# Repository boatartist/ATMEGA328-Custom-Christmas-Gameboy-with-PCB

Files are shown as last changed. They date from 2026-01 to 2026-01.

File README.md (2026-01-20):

# ATMEGA328-Custom-Christmas-Gameboy-with-PCB



For Christmas every year, I try to make each member of my family something unique, showing off my technical ability and giving them something personalised. However, as I get older and my skills improve, the time taken to make an original gift for all 7+ members of my close family increases exponentially. Instead, I thought I might try making everyone the same thing this year, and customising the product to fit their tastes. I landed on a gameboy-style Arduino-based console, possibly with only one game each, with unique 3D-printed enclosures and different games to match each person. Because I'm cheap, we will not be using reliable and standard OLED displays and an Arduino Nano or similar, instead I've gone for an obscure TFT-LCD from Digikey and an ATMEGA328-PU chip to achieve the same goals. 

Of course, there will also be a custom PCB (with factory PCB assembly because my soldering iron is rubbish) to house the display, buttons and microcontroller. And, of course, I have hugely overestimated my own knowledge and gone down an extreme rabbit-hole of fuse-bits and ISPs and oscillators thinking I'd broken the chips. If you're using Arduino ISP, be warned because it will cause a ridiculous amount of problems.

## Parts
All links to where I ordered from (I ordered for 10 modules), which came out to about AUD$250 with shipping, PCB and assembly, but the parts themselves are the cheapest I could find. Probably shouldn't have ordered from 3 separate sources lol, but the $25 each is still cheaper than any existing product. 

Each board contains: 
- [ATMEGA328-PU](https://www.digikey.com.au/en/products/detail/microchip-technology/ATMEGA328-PU/2271026)
- 6 x [3.3K Ohm through-hole resistor](https://www.digikey.com.au/en/products/detail/koa-speer-electronics-inc/MF1-4LCT52R332J/21680116)
- 6 x [2.2K Ohm through-hole resistor](https://www.digikey.com.au/en/products/detail/te-connectivity-passive-product/CFR50J2K2/2380663)
- [Battery holder for 3 x AAA batteries](https://www.digikey.com.au/en/products/detail/keystone-electronics/2479/303824)
- [320x240 ST7789 TFT LCD](https://www.lcsc.com/product-detail/C5329582.html)
- 6 x [push buttons](https://www.lcsc.com/product-detail/C22375351.html)
- [IC Socket for ATMEGA328](https://www.lcsc.com/product-detail/C72125.html)
- [FFC Connector for display](https://www.lcsc.com/product-detail/C2911796.html)

## Steps to program using [ISP](https://www.jaycar.com.au/duinotech-isp-programmer-for-arduino-and-avr/p/XC4627)
1. Set up ISP (In-System Programmer) according to [manual](https://media.jaycar.com.au/product/resources/XC4627_manualMain_86841.pdf), configuring with latest version of USB-ASP
2. Install [AVRDUDESS](https://atmega32-avr.com/avrdudess-a-gui-for-avrdude/) and set fuses and settings to match screenshots exactly  
3. Download gameboy_snake.hex file and select it to be flashed
4. Wire ATMega328 on breadboard to connect to ISP pins
  
  | ISP Pin       | ATMega328 Pin |
  | ------------- | ------------- |
  | MISO          | 18            |
  | MOSI          | 17            |
  | SCK           | 19            |
  | RST           | 1             |
  | VCC           | 7             |
  | GND           | 8             |

5. Hit **Program** on AVRDUDESS and watch code flash to the chip
6. Disconnect ATMega328 from breadboard and plug into PCB, attach batteries and enjoy! 

## Wiring diagram
Schematic_gameboy-christmas-project-with-ATMEGA328-and-MF128128F15-BFW_2026-01-20

## PCB
Download Gerber and/or order details from files

Photo-View_2025-11-28
<?xml version="1.0" encoding="utf-8" standalone="no"?><svg xmlns="http://www.w3.org/2000/svg" xmlns:xlink="http://www.w3.org/1999/xlink" width="50.08890017780036mm" height="125.06985013970029mm" viewBox="4010 3386 197.2 492.4"><rect x="4010" y="3386" width="197.2" height="492.4" fill="#FFFFFF" stroke="none"/><defs xmlns="http://www.w3.org/2000/svg" id="patterns"><pattern id="gridPattern" x="4000" y="3000" width="10" height="10" patternUnits="userSpaceOnUse"><rect id="gridCell" x="0" y="0" width="0.7143" height="0.7143" fill="#FFFFFF" stroke="none"/></pattern><pattern id="gridPattern2" x="4000.7143" y="3000.7143" width="10" height="10" patternUnits="userSpaceOnUse"><path id="gridCell2" d="M10 0V10H-10" fill="none" stroke="#FFFFFF" stroke-width="0.7143" stroke-opacity="0.6"/></pattern><marker id="arrowOnStart" orient="auto" refY="0" refX="0" style="overflow:visible" markerUnits="strokeWidth"><path d="M 2,0 l 4,-2, 0,4 z" stroke-width="6"/></marker><marker id="arrowOnEnd" orient="auto" refY="0" refX="0" style="overflow:visible" markerUnits="strokeWidth"><path d="M -2,0 l -4,-2, 0,4 z" stroke-width="6"/></marker><marker id="arrowOnStartChrome" orient="auto" refY="0" refX="0" style="overflow:visible" markerUnits="strokeWidth"><path d="M 2,0 l 4,-2, 0,4 z" stroke-width="3" stroke="#FFFFFF"/></marker><marker id="arrowOnEndChrome" orient="auto" refY="0" refX="0" style="overflow:visible" markerUnits="strokeWidth"><path d="M -2,0 l -4,-2, 0,4 z" stroke-width="3" stroke="#FFFFFF"/></marker><svg id="icon-lock" title="Unlock" viewBox="0 0 20 20" height="20" width="20"><path stroke="#F0F" stroke-width="2" style="cursor:pointer;fill-opacity:.001;fill:#fff" d="M 5 7 C 5 -1 15 -1 15 7L1 7 1 19 19 19 19 7 15 7"/></svg><mask id="multiLayerMask" maskUnits="userSpaceOnUse" x="4020" y="3396" width="177.2" height="472.4"><path d="M4035.7493 3868.44,4035.3938 3868.4359,4035.3881 3868.4357,4035.0416 3868.4241,4035.036 3868.4238,4034.6849 3868.404,4034.6794 3868.4036,4034.3336 3868.3762,4034.328 3868.3757,4033.9828 3868.3407,4033.9771 3868.3401,4033.6243 3868.2961,4033.6186 3868.2953,4033.2793 3868.2451,4033.2739 3868.2443,4032.9234 3868.1846,4032.9178 3868.1835,4032.5809 3868.1181,4032.5754 3868.117,4032.2322 3868.0425,4032.2267 3868.0412,4031.8857 3867.959,4031.8801 3867.9576,4031.5416 3867.8677,4031.5363 3867.8662,4031.2031 3867.7699,4031.1976 3867.7682,4030.8647 3867.6636,4030.8595 3867.6619,4030.5274 3867.5494,4030.522 3867.5475,4030.1925 3867.4275,4030.1871 3867.4255,4029.8629 3867.2989,4029.8577 3867.2968,4029.538 3867.1638,4029.5328 3867.1616,4029.2094 3867.0183,4029.2043 3867.0159,4028.8911 3866.8688,4028.8861 3866.8663,4028.5712 3866.7096,4028.566 3866.707,4028.2579 3866.5447,4028.2531 3866.542,4027.9474 3866.3722,4027.9425 3866.3695,4027.6422 3866.1938,4027.6373 3866.1908,4027.3381 3866.0063,4027.3333 3866.0033,4027.0435 3865.8155,4027.039 3865.8125,4026.745 3865.6127,4026.7403 3865.6094,4026.4594 3865.409,4026.4549 3865.4057,4026.1728 3865.1946,4026.1683 3865.1912,4025.8984 3864.9796,4025.894 3864.976,4025.6166 3864.7482,4025.6123 3864.7446,4025.3533 3864.522,4025.3491 3864.5183,4025.0882 3864.2837,4025.084 3864.2799,4024.8293 3864.0401,4024.8253 3864.0363,4024.5751 3863.79,4024.571 3863.7859,4024.3292 3863.5367,4024.3253 3863.5327,4024.0889 3863.278,4024.0852 3863.2739,4023.8503 3863.009,4023.8466 3863.0048,4023.6243 3862.7426,4023.6206 3862.7383,4023.3976 3862.4627,4023.3942 3862.4582,4023.1824 3862.1844,4023.179 3862.1799,4022.9715 3861.8984,4022.9683 3861.8939,4022.7651 3861.605,4022.7619 3861.6004,4022.569 3861.3125,4022.5659 3861.3078,4022.3796 3861.0159,4022.3765 3861.011,4022.195 3860.7116,4022.1922 3860.7068,4022.0156 3860.4005,4022.0128 3860.3955,4021.8473 3860.0927,4021.8447 3860.0877,4021.6827 3859.7749,4021.6802 3859.7699,4021.5282 3859.4593,4021.5258 3859.4542,4021.3762 3859.1301,4021.3739 3859.125,4021.2371 3858.8105,4021.2348 3858.8052,4021.1025 3858.4807,4021.1005 3858.4755,4020.9772 3858.153,4020.9752 3858.1477,4020.8556 3857.8123,4020.8537 3857.8069,4020.7462 3857.4821,4020.7446 3857.4768,4020.6401 3857.1361,4020.6385 3857.1307,4020.5453 3856.8,4020.5438 3856.7945,4020.4554 3856.4514,4020.4541 3856.446,4020.3751 3856.1089,4020.3738 3856.1033,4020.3021 3855.7617,4020.301 3855.7562,4020.2363 3855.4102,4020.2354 3855.4046,4020.1794 3855.0624,4020.1785 3855.0568,4020.1302 3854.7123,4020.1294 3854.7067,4020.0885 3854.3589,4020.0879 3854.3533,4020.0547 3854.0033,4020.0543 3853.9977,4020.0291 3853.6509,4020.0288 3853.6451,4020.0115 3853.2947,4020.0113 3853.2891,4020.002 3852.9426,4020.0019 3852.9377,4019.9999 3852.691,4020 3852.689,4020 3411.7504,4019.9999 3411.7476,4020.004 3411.3938,4020.0042 3411.3881,4020.0158 3411.0416,4020.0161 3411.036,4020.0359 3410.6849,4020.0363 3410.6794,4020.0637 3410.3336,4020.0642 3410.328,4020.0992 3409.9828,4020.0998 3409.9771,4020.1438 3409.6243,4020.1446 3409.6186,4020.1948 3409.2793,4020.1956 3409.2739,4020.2553 3408.9234,4020.2564 3408.9178,4020.3218 3408.5809,4020.3229 3408.5754,4020.3974 3408.2322,4020.3987 3408.2267,4020.4809 3407.8857,4020.4823 3407.8801,4020.5722 3407.5416,4020.5737 3407.5363,4020.67 3407.2031,4020.6717 3407.1976,4020.7763 3406.8647,4020.778 3406.8595,4020.8905 3406.5274,4020.8924 3406.522,4021.0124 3406.1925,4021.0144 3406.1871,4021.141 3405.8629,4021.1431 3405.8577,4021.2761 3405.538,4021.2783 3405.5328,4021.4216 3405.2094,4021.424 3405.2043,4021.5711 3404.8911,4021.5736 3404.8861,4021.7303 3404.5712,4021.7329 3404.566,4021.8952 3404.2579,4021.8979 3404.2531,4022.0677 3403.9474,4022.0704 3403.9425,4022.2461 3403.6422,4022.2491 3403.6373,4022.4336 3403.3381,4022.4366 3403.3333,4022.6244 3403.0435,4022.6274 3403.039,4022.8272 3402.745,4022.8305 3402.7403,4023.0309 3402.4594,4023.0342 3402.4549,4023.2453 3402.1728,4023.2487 3402.1683,4023.4593 3401.8996,4023.4628 3401.8952,4023.6917 3401.6165,4023.6953 3401.6123,4023.9179 3401.3533,4023.9216 3401.3491,4024.1562 3401.0882,4024.16 3401.084,4024.3998 3400.8293,4024.4036 3400.8253,4024.6499 3400.5751,4024.654 3400.571,4024.9032 3400.3292,4024.9072 3400.3253,4025.1619 3400.0889,4025.166 3400.0852,4025.4309 3399.8503,4025.4351 3399.8466,4025.6973 3399.6243,4025.7016 3399.6206,4025.9772 3399.3976,4025.9817 3399.3942,4026.2555 3399.1824,4026.26 3399.179,4026.5415 3398.9715,4026.546 3398.9683,4026.8349 3398.7651,4026.8395 3398.7619,4027.1274 3398.569,4027.1321 3398.5659,4027.424 3398.3796,4027.4289 3398.3765,4027.7283 3398.195,4027.7331 3398.1922,4028.0394 3398.0156,4028.0444 3398.0128,4028.3472 3397.8473,4028.3522 3397.8447,4028.665 3397.6827,4028.67 3397.6802,4028.9806 3397.5282,4028.9857 3397.5257,4029.309 3397.3765,4029.314 3397.3743,4029.6293 3397.2371,4029.6347 3397.2348,4029.9592 3397.1025,4029.9644 3397.1005,4030.2869 3396.9772,4030.2922 3396.9752,4030.6276 3396.8556,4030.633 3396.8537,4030.9578 3396.7462,4030.9631 3396.7446,4031.3038 3396.6401,4031.3092 3396.6385,4031.6399 3396.5453,4031.6454 3396.5438,4031.9885 3396.4554,4031.9939 3396.4541,4032.331 3396.3751,4032.3366 3396.3738,4032.6782 3396.3021,4032.6837 3396.301,4033.0297 3396.2363,4033.0353 3396.2354,4033.3775 3396.1794,4033.3831 3396.1785,4033.7276 3396.1302,4033.7332 3396.1294,4034.081 3396.0885,4034.0866 3396.0879,4034.4366 3396.0547,4034.4422 3396.0543,4034.789 3396.0291,4034.7948 3396.0288,4035.1452 3396.0115,4035.1508 3396.0113,4035.4973 3396.002,4035.5022 3396.0019,4035.7489 3395.9999,4035.7509 3396,4181.4128 3396,4181.4156 3395.9999,4181.7711 3396.004,4181.7768 3396.0042,4182.1233 3396.0158,4182.1289 3396.0161,4182.48 3396.0359,4182.4855 3396.0363,4182.8313 3396.0637,4182.8369 3396.0642,4183.1821 3396.0992,4183.1878 3396.0998,4183.5406 3396.1438,4183.5463 3396.1446,4183.8856 3396.1948,4183.891 3396.1956,4184.2415 3396.2553,4184.2471 3396.2564,4184.584 3396.3218,4184.5895 3396.3229,4184.9327 3396.3974,4184.9382 3396.3987,4185.2792 3396.4809,4185.2848 3396.4823,4185.6233 3396.5722,4185.6286 3396.5737,4185.9618 3396.67,4185.9673 3396.6717,4186.3002 3396.7763,4186.3054 3396.778,4186.6375 3396.8905,4186.6429 3396.8924,4186.9724 3397.0124,4186.9778 3397.0144,4187.302 3397.141,4187.3072 3397.1431,4187.6269 3397.2761,4187.6321 3397.2783,4187.9555 3397.4216,4187.9606 3397.424,4188.2738 3397.5711,4188.2788 3397.5736,4188.5937 3397.7303,4188.5989 3397.7329,4188.907 3397.8952,4188.9118 3397.8979,4189.2175 3398.0677,4189.2224 3398.0704,4189.5227 3398.2461,4189.5276 3398.2491,4189.8268 3398.4336,4189.8316 3398.4366,4190.1214 3398.6244,4190.1259 3398.6274,4190.4199 3398.8272,4190.4246 3398.8305,4190.7055 3399.0309,4190.71 3399.0342,4190.9921 3399.2453,4190.9966 3399.2487,4191.2665 3399.4603,4191.2709 3399.4639,4191.5483 3399.6917,4191.5526 3399.6953,4191.8116 3399.9179,4191.8158 3399.9216,4192.0767 3400.1562,4192.0809 3400.16,4192.3356 3400.3998,4192.3396 3400.4036,4192.5898 3400.6499,4192.5939 3400.654,4192.8357 3400.9032,4192.8396 3400.9072,4193.076 3401.1619,4193.0797 3401.166,4193.3146 3401.4309,4193.3183 3401.4351,4193.5406 3401.6973,4193.5443 3401.7016,4193.7673 3401.9772,4193.7707 3401.9817,4193.9825 3402.2555,4193.9859 3402.26,4194.1924 3402.5401,4194.1956 3402.5446,4194.3998 3402.8349,4194.403 3402.8395,4194.5959 3403.1274,4194.599 3403.1321,4194.7853 3403.424,4194.7884 3403.4289,4194.9699 3403.7283,4194.9727 3403.7331,4195.1493 3404.0394,4195.1521 3404.0444,4195.3176 3404.3472,4195.3202 3404.3522,4195.4822 3404.665,4195.4847 3404.67,4195.6367 3404.9806,4195.6391 3404.9857,4195.7887 3405.3098,4195.791 3405.3149,4195.9278 3405.6294,4195.9301 3405.6347,4196.0624 3405.9592,4196.0644 3405.9644,4196.1877 3406.2869,4196.1897 3406.2922,4196.3093 3406.6276,4196.3111 3406.6329,4196.4181 3406.9559,4196.4199 3406.9613,4196.5249 3407.3038,4196.5264 3407.3092,4196.6196 3407.6399,4196.6211 3407.6454,4196.7095 3407.9885,4196.7108 3407.9939,4196.7898 3408.331,4196.7911 3408.3366,4196.8628 3408.6782,4196.8639 3408.6837,4196.9286 3409.0297,4196.9295 3409.0353,4196.9855 3409.3775,4196.9864 3409.3831,4197.0347 3409.7276,4197.0355 3409.7332,4197.0764 3410.081,4197.077 3410.0866,4197.1102 3410.4366,4197.1106 3410.4422,4197.1358 3410.789,4197.1361 3410.7948,4197.1534 3411.1452,4197.1536 3411.1508,4197.1629 3411.4973,4197.163 3411.5021,4197.165 3411.7449,4197.165 3852.6906,4197.1609 3853.0461,4197.1607 3853.0518,4197.1491 3853.3983,4197.1488 3853.4039,4197.129 3853.755,4197.1286 3853.7605,4197.1012 3854.1063,4197.1007 3854.1119,4197.0657 3854.4571,4197.0651 3854.4628,4197.0211 3854.8156,4197.0203 3854.8213,4196.9701 3855.1606,4196.9693 3855.166,4196.9096 3855.5165,4196.9085 3855.5221,4196.8431 3855.859,4196.842 3855.8645,4196.7675 3856.2077,4196.7662 3856.2132,4196.684 3856.5542,4196.6826 3856.5598,4196.5927 3856.8983,4196.5912 3856.9036,4196.4949 3857.2368,4196.4932 3857.2423,4196.3886 3857.5752,4196.3869 3857.5804,4196.2744 3857.9125,4196.2725 3857.9179,4196.1525 3858.2474,4196.1505 3858.2528,4196.0239 3858.577,4196.0218 3858.5822,4195.8888 3858.9019,4195.8866 3858.9071,4195.7433 3859.2305,4195.7409 3859.2356,4195.5938 3859.5488,4195.5913 3859.5538,4195.4346 3859.8687,4195.432 3859.8739,4195.2697 3860.182,4195.267 3860.1868,4195.0972 3860.4925,4195.0945 3860.4974,4194.9188 3860.7977,4194.9158 3860.8026,4194.7313 3861.1018,4194.7283 3861.1066,4194.5405 3861.3964,4194.5375 3861.4009,4194.3377 3861.6949,4194.3344 3861.6996,4194.134 3861.9805,4194.1307 3861.985,4193.9196 3862.2671,4193.9162 3862.2716,4193.7056 3862.5403,4193.7021 3862.5447,4193.4736 3862.8229,4193.47 3862.8271,4193.247 3863.0866,4193.2433 3863.0908,4193.0087 3863.3517,4193.0049 3863.3559,4192.7651 3863.6106,4192.7613 3863.6146,4192.515 3863.8648,4192.5109 3863.8689,4192.2617 3864.1107,4192.2577 3864.1146,4192.003 3864.351,4191.9989 3864.3547,4191.734 3864.5896,4191.7298 3864.5933,4191.4676 3864.8156,4191.4633 3864.8193,4191.1877 3865.0423,4191.1832 3865.0457,4190.9094 3865.2575,4190.9049 3865.2609,4190.6234 3865.4684,4190.6189 3865.4716,4190.33 3865.6748,4190.3254 3865.678,4190.0375 3865.8709,4190.0328 3865.874,4189.7409 3866.0603,4189.736 3866.0634,4189.4366 3866.2449,4189.4318 3866.2477,4189.1255 3866.4243,4189.1205 3866.4271,4188.8177 3866.5926,4188.8127 3866.5952,4188.4999 3866.7572,4188.4949 3866.7597,4188.1843 3866.9117,4188.1792 3866.9142,4187.8559 3867.0634,4187.8509 3867.0656,4187.5356 3867.2028,4187.5302 3867.2051,4187.2057 3867.3374,4187.2005 3867.3394,4186.878 3867.4627,4186.8727 3867.4647,4186.5373 3867.5843,4186.5319 3867.5862,4186.2071 3867.6937,4186.2018 3867.6953,4185.8611 3867.7998,4185.8557 3867.8014,4185.525 3867.8946,4185.5195 3867.8961,4185.1764 3867.9845,4185.171 3867.9858,4184.8339 3868.0648,4184.8283 3868.0661,4184.4867 3868.1378,4184.4812 3868.1389,4184.1352 3868.2036,4184.1296 3868.2045,4183.7874 3868.2605,4183.7818 3868.2614,4183.4373 3868.3097,4183.4317 3868.3105,4183.0839 3868.3514,4183.0783 3868.352,4182.7283 3868.3852,4182.7227 3868.3856,4182.3759 3868.4108,4182.3701 3868.4111,4182.0197 3868.4284,4182.0141 3868.4286,4181.6676 3868.4379,4181.6627 3868.438,4181.416 3868.44z" stroke="none" fill="white"/><g fill="black"><circle cx="4099.725" cy="3793.231" r="0.6" stroke-width="0"/><circle cx="4109.039" cy="3687.587" r="0.6" stroke-width="0"/><circle cx="4094.948" cy="3731.755" r="0.6" stroke-width="0"/><circle cx="4060.229" cy="3753.04" r="0.6" stroke-width="0"/><circle cx="4132.822" cy="3792.35" r="0.6" stroke-width="0"/><circle cx="4159.1729" cy="3600.724" r="2.7559" stroke-width="0"/><circle cx="4109.173" cy="3600.724" r="2.7559" stroke-width="0"/><circle cx="4027.4811" cy="3797.574" r="1.5748" stroke-width="0"/><circle cx="4067.6369" cy="3797.574" r="1.5748" stroke-width="0"/><circle cx="4086.5361" cy="3797.574" r="1.5748" stroke-width="0"/><circle cx="4126.6919" cy="3797.574" r="1.5748" stroke-width="0"/><circle cx="4145.5911" cy="3797.574" r="1.5748" stroke-width="0"/><circle cx="4185.7469" cy="3797.574" r="1.5748" stroke-width="0"/><circle cx="4027.4811" cy="3858.5975" r="1.5748" stroke-width="0"/><circle cx="4067.6369" cy="3858.5975" r="1.5748" stroke-width="0"/><circle cx="4086.5361" cy="3858.5975" r="1.5748" stroke-width="0"/><circle cx="4126.6919" cy="3858.5975" r="1.5748" stroke-width="0"/><circle cx="4145.5911" cy="3858.5975" r="1.5748" stroke-width="0"/><circle cx="4185.7469" cy="3858.5975" r="1.5748" stroke-width="0"/><circle cx="4094.4101" cy="3773.952" r="1.5748" stroke-width="0"/><circle cx="4134.5659" cy="3773.952" r="1.5748" stroke-width="0"/><circle cx="4149.5281" cy="3773.952" r="1.5748" stroke-width="0"/><circle cx="4189.6839" cy="3773.952" r="1.5748" stroke-width="0"/><circle cx="4149.5281" cy="3750.33" r="1.5748" stroke-width="0"/><circle cx="4189.6839" cy="3750.33" r="1.5748" stroke-width="0"/><circle cx="4149.5281" cy="3691.275" r="1.5748" stroke-width="0"/><circle cx="4189.6839" cy="3691.275" r="1.5748" stroke-width="0"/><circle cx="4149.5281" cy="3671.59" r="1.5748" stroke-width="0"/><circle cx="4189.6839" cy="3671.59" r="1.5748" stroke-width="0"/><circle cx="4031.4181" cy="3691.275" r="1.5748" stroke-width="0"/><circle cx="4071.5739" cy="3691.275" r="1.5748" stroke-width="0"/><circle cx="4043.5825" cy="3844.07" r="1.9685" stroke-width="0"/><circle cx="4053.5825" cy="3844.07" r="1.9685" stroke-width="0"/><circle cx="4063.5825" cy="3844.07" r="1.9685" stroke-width="0"/><circle cx="4073.5825" cy="3844.07" r="1.9685" stroke-width="0"/><circle cx="4083.5825" cy="3844.07" r="1.9685" stroke-width="0"/><circle cx="4093.5825" cy="3844.07" r="1.9685" stroke-width="0"/><circle cx="4103.5825" cy="3844.07" r="1.9685" stroke-width="0"/><circle cx="4113.5825" cy="3844.07" r="1.9685" stroke-width="0"/><circle cx="4123.5825" cy="3844.07" r="1.9685" stroke-width="0"/><circle cx="4133.5825" cy="3844.07" r="1.9685" stroke-width="0"/><circle cx="4143.5825" cy="3844.07" r="1.9685" stroke-width="0"/><circle cx="4153.5825" cy="3844.07" r="1.9685" stroke-width="0"/><circle cx="4163.5825" cy="3844.07" r="1.9685" stroke-width="0"/><circle cx="4173.5825" cy="3844.07" r="1.9685" stroke-width="0"/><circle cx="4173.5825" cy="3814.07" r="1.9685" stroke-width="0"/><circle cx="4163.5825" cy="3814.07" r="1.9685" stroke-width="0"/><circle cx="4153.5825" cy="3814.07" r="1.9685" stroke-width="0"/><circle cx="4143.5825" cy="3814.07" r="1.9685" stroke-width="0"/><circle cx="4133.5825" cy="3814.07" r="1.9685" stroke-width="0"/><circle cx="4123.5825" cy="3814.07" r="1.9685" stroke-width="0"/><circle cx="4113.5825" cy="3814.07" r="1.9685" stroke-width="0"/><circle cx="4103.5825" cy="3814.07" r="1.9685" stroke-width="0"/><circle cx="4093.5825" cy="3814.07" r="1.9685" stroke-width="0"/><circle cx="4083.5825" cy="3814.07" r="1.9685" stroke-width="0"/><circle cx="4073.5825" cy="3814.07" r="1.9685" stroke-width="0"/><circle cx="4063.5825" cy="3814.07" r="1.9685" stroke-width="0"/><circle cx="4053.5825" cy="3814.07" r="1.9685" stroke-width="0"/><circle cx="4043.5825" cy="3814.07" r="1.9685" stroke-width="0"/><circle cx="4185.354" cy="3632.22" r="4.3307" stroke-width="0"/><circle cx="4031.811" cy="3632.22" r="4.3307" stroke-width="0"/></g></mask><mask id="topBoardSolderMask" maskUnits="userSpaceOnUse" x="4020" y="3396" width="177.2" height="472.4"><path d="M4035.7493 3868.44,4035.3938 3868.4359,4035.3881 3868.4357,4035.0416 3868.4241,4035.036 3868.4238,4034.6849 3868.404,4034.6794 3868.4036,4034.3336 3868.3762,4034.328 3868.3757,4033.9828 3868.3407,4033.9771 3868.3401,4033.6243 3868.2961,4033.6186 3868.2953,4033.2793 3868.2451,4033.2739 3868.2443,4032.9234 3868.1846,4032.9178 3868.1835,4032.5809 3868.1181,4032.5754 3868.117,4032.2322 3868.0425,4032.2267 3868.0412,4031.8857 3867.959,4031.8801 3867.9576,4031.5416 3867.8677,4031.5363 3867.8662,4031.2031 3867.7699,4031.1976 3867.7682,4030.8647 3867.6636,4030.8595 3867.6619,4030.5274 3867.5494,4030.522 3867.5475,4030.1925 3867.4275,4030.1871 3867.4255,4029.8629 3867.2989,4029.8577 3867.2968,4029.538 3867.1638,4029.5328 3867.1616,4029.2094 3867.0183,4029.2043 3867.0159,4028.8911 3866.8688,4028.8861 3866.8663,4028.5712 3866.7096,4028.566 3866.707,4028.2579 3866.5447,4028.2531 3866.542,4027.9474 3866.3722,4027.9425 3866.3695,4027.6422 3866.1938,4027.6373 3866.1908,4027.3381 3866.0063,4027.3333 3866.0033,4027.0435 3865.8155,4027.039 3865.8125,4026.745 3865.6127,4026.7403 3865.6094,4026.4594 3865.409,4026.4549 3865.4057,4026.1728 3865.1946,4026.1683 3865.1912,4025.8984 3864.9796,4025.894 3864.976,4025.6166 3864.7482,4025.6123 3864.7446,4025.3533 3864.522,4025.3491 3864.5183,4025.0882 3864.2837,4025.084 3864.2799,4024.8293 3864.0401,4024.8253 3864.0363,4024.5751 3863.79,4024.571 3863.7859,4024.3292 3863.5367,4024.3253 3863.5327,4024.0889 3863.278,4024.0852 3863.2739,4023.8503 3863.009,4023.8466 3863.0048,4023.6243 3862.7426,4023.6206 3862.7383,4023.3976 3862.4627,4023.3942 3862.4582,4023.1824 3862.1844,4023.179 3862.1799,4022.9715 3861.8984,4022.9683 3861.8939,4022.7651 3861.605,4022.7619 3861.6004,4022.569 3861.3125,4022.5659 3861.3078,4022.3796 3861.0159,4022.3765 3861.011,4022.195 3860.7116,4022.1922 3860.7068,4022.0156 3860.4005,4022.0128 3860.3955,4021.8473 3860.0927,4021.8447 3860.0877,4021.6827 3859.7749,4021.6802 3859.7699,4021.5282 3859.4593,4021.5258 3859.4542,4021.3762 3859.1301,4021.3739 3859.125,4021.2371 3858.8105,4021.2348 3858.8052,4021.1025 3858.4807,4021.1005 3858.4755,4020.9772 3858.153,4020.9752 3858.1477,4020.8556 3857.8123,4020.8537 3857.8069,4020.7462 3857.4821,4020.7446 3857.4768,4020.6401 3857.1361,4020.6385 3857.1307,4020.5453 3856.8,4020.5438 3856.7945,4020.4554 3856.4514,4020.4541 3856.446,4020.3751 3856.1089,4020.3738 3856.1033,4020.3021 3855.7617,4020.301 3855.7562,4020.2363 3855.4102,4020.2354 3855.4046,4020.1794 3855.0624,4020.1785 3855.0568,4020.1302 3854.7123,4020.1294 3854.7067,4020.0885 3854.3589,4020.0879 3854.3533,4020.0547 3854.0033,4020.0543 3853.9977,4020.0291 3853.6509,4020.0288 3853.6451,4020.0115 3853.2947,4020.0113 3853.2891,4020.002 3852.9426,4020.0019 3852.9377,4019.9999 3852.691,4020 3852.689,4020 3411.7504,4019.9999 3411.7476,4020.004 3411.3938,4020.0042 3411.3881,4020.0158 3411.0416,4020.0161 3411.036,4020.0359 3410.6849,4020.0363 3410.6794,4020.0637 3410.3336,4020.0642 3410.328,4020.0992 3409.9828,4020.0998 3409.9771,4020.1438 3409.6243,4020.1446 3409.6186,4020.1948 3409.2793,4020.1956 3409.2739,4020.2553 3408.9234,4020.2564 3408.9178,4020.3218 3408.5809,4020.3229 3408.5754,4020.3974 3408.2322,4020.3987 3408.2267,4020.4809 3407.8857,4020.4823 3407.8801,4020.5722 3407.5416,4020.5737 3407.5363,4020.67 3407.2031,4020.6717 3407.1976,4020.7763 3406.8647,4020.778 3406.8595,4020.8905 3406.5274,4020.8924 3406.522,4021.0124 3406.1925,4021.0144 3406.1871,4021.141 3405.8629,4021.1431 3405.8577,4021.2761 3405.538,4021.2783 3405.5328,4021.4216 3405.2094,4021.424 3405.2043,4021.5711 3404.8911,4021.5736 3404.8861,4021.7303 3404.5712,4021.7329 3404.566,4021.8952 3404.2579,4021.8979 3404.2531,4022.0677 3403.9474,4022.0704 3403.9425,4022.2461 3403.6422,4022.2491 3403.6373,4022.4336 3403.3381,4022.4366 3403.3333,4022.6244 3403.0435,4022.6274 3403.039,4022.8272 3402.745,4022.8305 3402.7403,4023.0309 3402.4594,4023.0342 3402.4549,4023.2453 3402.1728,4023.2487 3402.1683,4023.4593 3401.8996,4023.4628 3401.8952,4023.6917 3401.6165,4023.6953 3401.6123,4023.9179 3401.3533,4023.9216 3401.3491,4024.1562 3401.0882,4024.16 3401.084,4024.3998 3400.8293,4024.4036 3400.8253,4024.6499 3400.5751,4024.654 3400.571,4024.9032 3400.3292,4024.9072 3400.3253,4025.1619 3400.0889,4025.166 3400.0852,4025.4309 3399.8503,4025.4351 3399.8466,4025.6973 3399.6243,4025.7016 3399.6206,4025.9772 3399.3976,4025.9817 3399.3942,4026.2555 3399.1824,4026.26 3399.179,4026.5415 3398.9715,4026.546 3398.9683,4026.8349 3398.7651,4026.8395 3398.7619,4027.1274 3398.569,4027.1321 3398.5659,4027.424 3398.3796,4027.4289 3398.3765,4027.7283 3398.195,4027.7331 3398.1922,4028.0394 3398.0156,4028.0444 3398.0128,4028.3472 3397.8473,4028.3522 3397.8447,4028.665 3397.6827,4028.67 3397.6802,4028.9806 3397.5282,4028.9857 3397.5257,4029.309 3397.3765,4029.314 3397.3743,4029.6293 3397.2371,4029.6347 3397.2348,4029.9592 3397.1025,4029.9644 3397.1005,4030.2869 3396.9772,4030.2922 3396.9752,4030.6276 3396.8556,4030.633 3396.8537,4030.9578 3396.7462,4030.9631 3396.7446,4031.3038 3396.6401,4031.3092 3396.6385,4031.6399 3396.5453,4031.6454 3396.5438,4031.9885 3396.4554,4031.9939 3396.4541,4032.331 3396.3751,4032.3366 3396.3738,4032.6782 3396.3021,4032.6837 3396.301,4033.0297 3396.2363,4033.0353 3396.2354,4033.3775 3396.1794,4033.3831 3396.1785,4033.7276 3396.1302,4033.7332 3396.1294,4034.081 3396.0885,4034.0866 3396.0879,4034.4366 3396.0547,4034.4422 3396.0543,4034.789 3396.0291,4034.7948 3396.0288,4035.1452 3396.0115,4035.1508 3396.0113,4035.4973 3396.002,4035.5022 3396.0019,4035.7489 3395.9999,4035.7509 3396,4181.4128 3396,4181.4156 3395.9999,4181.7711 3396.004,4181.7768 3396.0042,4182.1233 3396.0158,4182.1289 3396.0161,4182.48 3396.0359,4182.4855 3396.0363,4182.8313 3396.0637,4182.8369 3396.0642,4183.1821 3396.0992,4183.1878 3396.0998,4183.5406 3396.1438,4183.5463 3396.1446,4183.8856 3396.1948,4183.891 3396.1956,4184.2415 3396.2553,4184.2471 3396.2564,4184.584 3396.3218,4184.5895 3396.3229,4184.9327 3396.3974,4184.9382 3396.3987,4185.2792 3396.4809,4185.2848 3396.4823,4185.6233 3396.5722,4185.6286 3396.5737,4185.9618 3396.67,4185.9673 3396.6717,4186.3002 3396.7763,4186.3054 3396.778,4186.6375 3396.8905,4186.6429 3396.8924,4186.9724 3397.0124,4186.9778 3397.0144,4187.302 3397.141,4187.3072 3397.1431,4187.6269 3397.2761,4187.6321 3397.2783,4187.9555 3397.4216,4187.9606 3397.424,4188.2738 3397.5711,4188.2788 3397.5736,4188.5937 3397.7303,4188.5989 3397.7329,4188.907 3397.8952,4188.9118 3397.8979,4189.2175 3398.0677,4189.2224 3398.0704,4189.5227 3398.2461,4189.5276 3398.2491,4189.8268 3398.4336,4189.8316 3398.4366,4190.1214 3398.6244,4190.1259 3398.6274,4190.4199 3398.8272,4190.4246 3398.8305,4190.7055 3399.0309,4190.71 3399.0342,4190.9921 3399.2453,4190.9966 3399.2487,4191.2665 3399.4603,4191.2709 3399.4639,4191.5483 3399.6917,4191.5526 3399.6953,4191.8116 3399.9179,4191.8158 3399.9216,4192.0767 3400.1562,4192.0809 3400.16,4192.3356 3400.3998,4192.3396 3400.4036,4192.5898 3400.6499,4192.5939 3400.654,4192.8357 3400.9032,4192.8396 3400.9072,4193.076 3401.1619,4193.0797 3401.166,4193.3146 3401.4309,4193.3183 3401.4351,4193.5406 3401.6973,4193.5443 3401.7016,4193.7673 3401.9772,4193.7707 3401.9817,4193.9825 3402.2555,4193.9859 3402.26,4194.1924 3402.5401,4194.1956 3402.5446,4194.3998 3402.8349,4194.403 3402.8395,4194.5959 3403.1274,4194.599 3403.1321,4194.7853 3403.424,4194.7884 3403.4289,4194.9699 3403.7283,4194.9727 3403.7331,4195.1493 3404.0394,4195.1521 3404.0444,4195.3176 3404.3472,4195.3202 3404.3522,4195.4822 3404.665,4195.4847 3404.67,4195.6367 3404.9806,4195.6391 3404.9857,4195.7887 3405.3098,4195.791 3405.3149,4195.9278 3405.6294,4195.9301 3405.6347,4196.0624 3405.9592,4196.0644 3405.9644,4196.1877 3406.2869,4196.1897 3406.2922,4196.3093 3406.6276,4196.3111 3406.6329,4196.4181 3406.9559,4196.4199 3406.9613,4196.5249 3407.3038,4196.5264 3407.3092,4196.6196 3407.6399,4196.6211 3407.6454,4196.7095 3407.9885,4196.7108 3407.9939,4196.7898 3408.331,4196.7911 3408.3366,4196.8628 3408.6782,4196.8639 3408.6837,4196.9286 3409.0297,4196.9295 3409.0353,4196.9855 3409.3775,4196.9864 3409.3831,4197.0347 3409.7276,4197.0355 3409.7332,4197.0764 3410.081,4197.077 3410.0866,4197.1102 3410.4366,4197.1106 3410.4422,4197.1358 3410.789,4197.1361 3410.7948,4197.1534 3411.1452,4197.1536 3411.1508,4197.1629 3411.4973,4197.163 3411.5021,4197.165 3411.7449,4197.165 3852.6906,4197.1609 3853.0461,4197.1607 3853.0518,4197.1491 3853.3983,4197.1488 3853.4039,4197.129 3853.755,4197.1286 3853.7605,4197.1012 3854.1063,4197.1007 3854.1119,4197.0657 3854.4571,4197.0651 3854.4628,4197.0211 3854.8156,4197.0203 3854.8213,4196.9701 3855.1606,4196.9693 3855.166,4196.9096 3855.5165,4196.9085 3855.5221,4196.8431 3855.859,4196.842 3855.8645,4196.7675 3856.2077,4196.7662 3856.2132,4196.684 3856.5542,4196.6826 3856.5598,4196.5927 3856.8983,4196.5912 3856.9036,4196.4949 3857.2368,4196.4932 3857.2423,4196.3886 3857.5752,4196.3869 3857.5804,4196.2744 3857.9125,4196.2725 3857.9179,4196.1525 3858.2474,4196.1505 3858.2528,4196.0239 3858.577,4196.0218 3858.5822,4195.8888 3858.9019,4195.8866 3858.9071,4195.7433 3859.2305,4195.7409 3859.2356,4195.5938 3859.5488,4195.5913 3859.5538,4195.4346 3859.8687,4195.432 3859.8739,4195.2697 3860.182,4195.267 3860.1868,4195.0972 3860.4925,4195.0945 3860.4974,4194.9188 3860.7977,4194.9158 3860.8026,4194.7313 3861.1018,4194.7283 3861.1066,4194.5405 3861.3964,4194.5375 3861.4009,4194.3377 3861.6949,4194.3344 3861.6996,4194.134 3861.9805,4194.1307 3861.985,4193.9196 3862.2671,4193.9162 3862.2716,4193.7056 3862.5403,4193.7021 3862.5447,4193.4736 3862.8229,4193.47 3862.8271,4193.247 3863.0866,4193.2433 3863.0908,4193.0087 3863.3517,4193.0049 3863.3559,4192.7651 3863.6106,4192.7613 3863.6146,4192.515 3863.8648,4192.5109 3863.8689,4192.2617 3864.1107,4192.2577 3864.1146,4192.003 3864.351,4191.9989 3864.3547,4191.734 3864.5896,4191.7298 3864.5933,4191.4676 3864.8156,4191.4633 3864.8193,4191.1877 3865.0423,4191.1832 3865.0457,4190.9094 3865.2575,4190.9049 3865.2609,4190.6234 3865.4684,4190.6189 3865.4716,4190.33 3865.6748,4190.3254 3865.678,4190.0375 3865.8709,4190.0328 3865.874,4189.7409 3866.0603,4189.736 3866.0634,4189.4366 3866.2449,4189.4318 3866.2477,4189.1255 3866.4243,4189.1205 3866.4271,4188.8177 3866.5926,4188.8127 3866.5952,4188.4999 3866.7572,4188.4949 3866.7597,4188.1843 3866.9117,4188.1792 3866.9142,4187.8559 3867.0634,4187.8509 3867.0656,4187.5356 3867.2028,4187.5302 3867.2051,4187.2057 3867.3374,4187.2005 3867.3394,4186.878 3867.4627,4186.8727 3867.4647,4186.5373 3867.5843,4186.5319 3867.5862,4186.2071 3867.6937,4186.2018 3867.6953,4185.8611 3867.7998,4185.8557 3867.8014,4185.525 3867.8946,4185.5195 3867.8961,4185.1764 3867.9845,4185.171 3867.9858,4184.8339 3868.0648,4184.8283 3868.0661,4184.4867 3868.1378,4184.4812 3868.1389,4184.1352 3868.2036,4184.1296 3868.2045,4183.7874 3868.2605,4183.7818 3868.2614,4183.4373 3868.3097,4183.4317 3868.3105,4183.0839 3868.3514,4183.0783 3868.352,4182.7283 3868.3852,4182.7227 3868.3856,4182.3759 3868.4108,4182.3701 3868.4111,4182.0197 3868.4284,4182.0141 3868.4286,4181.6676 3868.4379,4181.6627 3868.438,4181.416 3868.44z" stroke="none" fill="white"/><g fill="black"><polygon points="4056.417 3716.082 4056.355 3716.072 4056.299 3716.044 4056.255 3716 4056.227 3715.944 4056.217 3715.882 4056.217 3709.976 4056.227 3709.914 4056.255 3709.858 4056.299 3709.814 4056.355 3709.786 4056.417 3709.776 4062.323 3709.776 4062.385 3709.786 4062.441 3709.814 4062.485 3709.858 4062.513 3709.914 4062.523 3709.976 4062.523 3715.882 4062.513 3715.944 4062.485 3716 4062.441 3716.044 4062.385 3716.072 4062.323 3716.082" stroke-width="0" c_etype="pad_outer"/><polygon points="4080.039 3716.082 4079.977 3716.072 4079.921 3716.044 4079.877 3716 4079.849 3715.944 4079.839 3715.882 4079.839 3709.976 4079.849 3709.914 4079.877 3709.858 4079.921 3709.814 4079.977 3709.786 4080.039 3709.776 4085.945 3709.776 4086.007 3709.786 4086.063 3709.814 4086.107 3709.858 4086.135 3709.914 4086.145 3709.976 4086.145 3715.882 4086.135 3715.944 4086.107 3716 4086.063 3716.044 4086.007 3716.072 4085.945 3716.082" stroke-width="0" c_etype="pad_outer"/><polygon points="4056.417 3727.892 4056.355 3727.882 4056.299 3727.854 4056.255 3727.81 4056.227 3727.754 4056.217 3727.692 4056.217 3721.786 4056.227 3721.724 4056.255 3721.668 4056.299 3721.624 4056.355 3721.596 4056.417 3721.586 4062.323 3721.586 4062.385 3721.596 4062.441 3721.624 4062.485 3721.668 4062.513 3721.724 4062.523 3721.786 4062.523 3727.692 4062.513 3727.754 4062.485 3727.81 4062.441 3727.854 4062.385 3727.882 4062.323 3727.892" stroke-width="0" c_etype="pad_outer"/><polygon points="4080.039 3727.892 4079.977 3727.882 4079.921 3727.854 4079.877 3727.81 4079.849 3727.754 4079.839 3727.692 4079.839 3721.786 4079.849 3721.724 4079.877 3721.668 4079.921 3721.624 4079.977 3721.596 4080.039 3721.586 4085.945 3721.586 4086.007 3721.596 4086.063 3721.624 4086.107 3721.668 4086.135 3721.724 4086.145 3721.786 4086.145 3727.692 4086.135 3727.754 4086.107 3727.81 4086.063 3727.854 4086.007 3727.882 4085.945 3727.892" stroke-width="0" c_etype="pad_outer"/><polygon points="4083.976 3743.641 4083.914 3743.631 4083.858 3743.603 4083.814 3743.559 4083.786 3743.503 4083.776 3743.441 4083.776 3737.535 4083.786 3737.473 4083.814 3737.417 4083.858 3737.373 4083.914 3737.345 4083.976 3737.335 4089.882 3737.335 4089.944 3737.345 4090 3737.373 4090.044 3737.417 4090.072 3737.473 4090.082 3737.535 4090.082 3743.441 4090.072 3743.503 4090.044 3743.559 4090 3743.603 4089.944 3743.631 4089.882 3743.641" stroke-width="0" c_etype="pad_outer"/><polygon points="4107.598 3743.641 4107.536 3743.631 4107.48 3743.603 4107.436 3743.559 4107.408 3743.503 4107.398 3743.441 4107.398 3737.535 4107.408 3737.473 4107.436 3737.417 4107.48 3737.373 4107.536 3737.345 4107.598 3737.335 4113.504 3737.335 4113.566 3737.345 4113.622 3737.373 4113.666 3737.417 4113.694 3737.473 4113.704 3737.535 4113.704 3743.441 4113.694 3743.503 4113.666 3743.559 4113.622 3743.603 4113.566 3743.631 4113.504 3743.641" stroke-width="0" c_etype="pad_outer"/><polygon points="4083.976 3755.451 4083.914 3755.441 4083.858 3755.413 4083.814 3755.369 4083.786 3755.313 4083.776 3755.251 4083.776 3749.345 4083.786 3749.283 4083.814 3749.227 4083.858 3749.183 4083.914 3749.155 4083.976 3749.145 4089.882 3749.145 4089.944 3749.155 4090 3749.183 4090.044 3749.227 4090.072 3749.283 4090.082 3749.345 4090.082 3755.251 4090.072 3755.313 4090.044 3755.369 4090 3755.413 4089.944 3755.441 4089.882 3755.451" stroke-width="0" c_etype="pad_outer"/><polygon points="4107.598 3755.451 4107.536 3755.441 4107.48 3755.413 4107.436 3755.369 4107.408 3755.313 4107.398 3755.251 4107.398 3749.345 4107.408 3749.283 4107.436 3749.227 4107.48 3749.183 4107.536 3749.155 4107.598 3749.145 4113.504 3749.145 4113.566 3749.155 4113.622 3749.183 4113.666 3749.227 4113.694 3749.283 4113.704 3749.345 4113.704 3755.251 4113.694 3755.313 4113.666 3755.369 4113.622 3755.413 4113.566 3755.441 4113.504 3755.451" stroke-width="0" c_etype="pad_outer"/><polygon points="4028.858 3743.641 4028.796 3743.631 4028.74 3743.603 4028.696 3743.559 4028.668 3743.503 4028.658 3743.441 4028.658 3737.535 4028.668 3737.473 4028.696 3737.417 4028.74 3737.373 4028.796 3737.345 4028.858 3737.335 4034.764 3737.335 4034.826 3737.345 4034.882 3737.373 4034.926 3737.417 4034.954 3737.473 4034.964 3737.535 4034.964 3743.441 4034.954 3743.503 4034.926 3743.559 4034.882 3743.603 4034.826 3743.631 4034.764 3743.641" stroke-width="0" c_etype="pad_outer"/><polygon points="4052.48 3743.641 4052.418 3743.631 4052.362 3743.603 4052.318 3743.559 4052.29 3743.503 4052.28 3743.441 4052.28 3737.535 4052.29 3737.473 4052.318 3737.417 4052.362 3737.373 4052.418 3737.345 4052.48 3737.335 4058.386 3737.335 4058.448 3737.345 4058.504 3737.373 4058.548 3737.417 4058.576 3737.473 4058.586 3737.535 4058.586 3743.441 4058.576 3743.503 4058.548 3743.559 4058.504 3743.603 4058.448 3743.631 4058.386 3743.641" stroke-width="0" c_etype="pad_outer"/><polygon points="4028.858 3755.451 4028.796 3755.441 4028.74 3755.413 4028.696 3755.369 4028.668 3755.313 4028.658 3755.251 4028.658 3749.345 4028.668 3749.283 4028.696 3749.227 4028.74 3749.183 4028.796 3749.155 4028.858 3749.145 4034.764 3749.145 4034.826 3749.155 4034.882 3749.183 4034.926 3749.227 4034.954 3749.283 4034.964 3749.345 4034.964 3755.251 4034.954 3755.313 4034.926 3755.369 4034.882 3755.413 4034.826 3755.441 4034.764 3755.451" stroke-width="0" c_etype="pad_outer"/><polygon points="4052.48 3755.451 4052.418 3755.441 4052.362 3755.413 4052.318 3755.369 4052.29 3755.313 4052.28 3755.251 4052.28 3749.345 4052.29 3749.283 4052.318 3749.227 4052.362 3749.183 4052.418 3749.155 4052.48 3749.145 4058.386 3749.145 4058.448 3749.155 4058.504 3749.183 4058.548 3749.227 4058.576 3749.283 4058.586 3749.345 4058.586 3755.251 4058.576 3755.313 4058.548 3755.369 4058.504 3755.413 4058.448 3755.441 4058.386 3755.451" stroke-width="0" c_etype="pad_outer"/><polygon points="4056.417 3771.2 4056.355 3771.19 4056.299 3771.162 4056.255 3771.118 4056.227 3771.062 4056.217 3771 4056.217 3765.094 4056.227 3765.032 4056.255 3764.976 4056.299 3764.932 4056.355 3764.904 4056.417 3764.894 4062.323 3764.894 4062.385 3764.904 4062.441 3764.932 4062.485 3764.976 4062.513 3765.032 4062.523 3765.094 4062.523 3771 4062.513 3771.062 4062.485 3771.118 4062.441 3771.162 4062.385 3771.19 4062.323 3771.2" stroke-width="0" c_etype="pad_outer"/><polygon points="4080.039 3771.2 4079.977 3771.19 4079.921 3771.162 4079.877 3771.118 4079.849 3771.062 4079.839 3771 4079.839 3765.094 4079.849 3765.032 4079.877 3764.976 4079.921 3764.932 4079.977 3764.904 4080.039 3764.894 4085.945 3764.894 4086.007 3764.904 4086.063 3764.932 4086.107 3764.976 4086.135 3765.032 4086.145 3765.094 4086.145 3771 4086.135 3771.062 4086.107 3771.118 4086.063 3771.162 4086.007 3771.19 4085.945 3771.2" stroke-width="0" c_etype="pad_outer"/><polygon points="4056.417 3783.01 4056.355 3783 4056.299 3782.972 4056.255 3782.928 4056.227 3782.872 4056.217 3782.81 4056.217 3776.904 4056.227 3776.842 4056.255 3776.786 4056.299 3776.742 4056.355 3776.714 4056.417 3776.704 4062.323 3776.704 4062.385 3776.714 4062.441 3776.742 4062.485 3776.786 4062.513 3776.842 4062.523 3776.904 4062.523 3782.81 4062.513 3782.872 4062.485 3782.928 4062.441 3782.972 4062.385 3783 4062.323 3783.01" stroke-width="0" c_etype="pad_outer"/><polygon points="4080.039 3783.01 4079.977 3783 4079.921 3782.972 4079.877 3782.928 4079.849 3782.872 4079.839 3782.81 4079.839 3776.904 4079.849 3776.842 4079.877 3776.786 4079.921 3776.742 4079.977 3776.714 4080.039 3776.704 4085.945 3776.704 4086.007 3776.714 4086.063 3776.742 4086.107 3776.786 4086.135 3776.842 4086.145 3776.904 4086.145 3782.81 4086.135 3782.872 4086.107 3782.928 4086.063 3782.972 4086.007 3783 4085.945 3783.01" stroke-width="0" c_etype="pad_outer"/><polygon points="4123.346 3723.956 4123.284 3723.946 4123.228 3723.918 4123.184 3723.874 4123.156 3723.818 4123.146 3723.756 4123.146 3717.85 4123.156 3717.788 4123.184 3717.732 4123.228 3717.688 4123.284 3717.66 4123.346 3717.65 4129.252 3717.65 4129.314 3717.66 4129.37 3717.688 4129.414 3717.732 4129.442 3717.788 4129.452 3717.85 4129.452 3723.756 4129.442 3723.818 4129.414 3723.874 4129.37 3723.918 4129.314 3723.946 4129.252 3723.956" stroke-width="0" c_etype="pad_outer"/><polygon points="4146.968 3723.956 4146.906 3723.946 4146.85 3723.918 4146.806 3723.874 4146.778 3723.818 4146.768 3723.756 4146.768 3717.85 4146.778 3717.788 4146.806 3717.732 4146.85 3717.688 4146.906 3717.66 4146.968 3717.65 4152.874 3717.65 4152.936 3717.66 4152.992 3717.688 4153.036 3717.732 4153.064 3717.788 4153.074 3717.85 4153.074 3723.756 4153.064 3723.818 4153.036 3723.874 4152.992 3723.918 4152.936 3723.946 4152.874 3723.956" stroke-width="0" c_etype="pad_outer"/><polygon points="4123.346 3735.766 4123.284 3735.756 4123.228 3735.728 4123.184 3735.684 4123.156 3735.628 4123.146 3735.566 4123.146 3729.66 4123.156 3729.598 4123.184 3729.542 4123.228 3729.498 4123.284 3729.47 4123.346 3729.46 4129.252 3729.46 4129.314 3729.47 4129.37 3729.498 4129.414 3729.542 4129.442 3729.598 4129.452 3729.66 4129.452 3735.566 4129.442 3735.628 4129.414 3735.684 4129.37 3735.728 4129.314 3735.756 4129.252 3735.766" stroke-width="0" c_etype="pad_outer"/><polygon points="4146.968 3735.766 4146.906 3735.756 4146.85 3735.728 4146.806 3735.684 4146.778 3735.628 4146.768 3735.566 4146.768 3729.66 4146.778 3729.598 4146.806 3729.542 4146.85 3729.498 4146.906 3729.47 4146.968 3729.46 4152.874 3729.46 4152.936 3729.47 4152.992 3729.498 4153.036 3729.542 4153.064 3729.598 4153.074 3729.66 4153.074 3735.566 4153.064 3735.628 4153.036 3735.684 4152.992 3735.728 4152.936 3735.756 4152.874 3735.766" stroke-width="0" c_etype="pad_outer"/><polygon points="4162.716 3723.956 4162.654 3723.946 4162.598 3723.918 4162.554 3723.874 4162.526 3723.818 4162.516 3723.756 4162.516 3717.85 4162.526 3717.788 4162.554 3717.732 4162.598 3717.688 4162.654 3717.66 4162.716 3717.65 4168.622 3717.65 4168.684 3717.66 4168.74 3717.688 4168.784 3717.732 4168.812 3717.788 4168.822 3717.85 4168.822 3723.756 4168.812 3723.818 4168.784 3723.874 4168.74 3723.918 4168.684 3723.946 4168.622 3723.956" stroke-width="0" c_etype="pad_outer"/><polygon points="4186.338 3723.956 4186.276 3723.946 4186.22 3723.918 4186.176 3723.874 4186.148 3723.818 4186.138 3723.756 4186.138 3717.85 4186.148 3717.788 4186.176 3717.732 4186.22 3717.688 4186.276 3717.66 4186.338 3717.65 4192.244 3717.65 4192.306 3717.66 4192.362 3717.688 4192.406 3717.732 4192.434 3717.788 4192.444 3717.85 4192.444 3723.756 4192.434 3723.818 4192.406 3723.874 4192.362 3723.918 4192.306 3723.946 4192.244 3723.956" stroke-width="0" c_etype="pad_outer"/><polygon points="4162.716 3735.766 4162.654 3735.756 4162.598 3735.728 4162.554 3735.684 4162.526 3735.628 4162.516 3735.566 4162.516 3729.66 4162.526 3729.598 4162.554 3729.542 4162.598 3729.498 4162.654 3729.47 4162.716 3729.46 4168.622 3729.46 4168.684 3729.47 4168.74 3729.498 4168.784 3729.542 4168.812 3729.598 4168.822 3729.66 4168.822 3735.566 4168.812 3735.628 4168.784 3735.684 4168.74 3735.728 4168.684 3735.756 4168.622 3735.766" stroke-width="0" c_etype="pad_outer"/><polygon points="4186.338 3735.766 4186.276 3735.756 4186.22 3735.728 4186.176 3735.684 4186.148 3735.628 4186.138 3735.566 4186.138 3729.66 4186.148 3729.598 4186.176 3729.542 4186.22 3729.498 4186.276 3729.47 4186.338 3729.46 4192.244 3729.46 4192.306 3729.47 4192.362 3729.498 4192.406 3729.542 4192.434 3729.598 4192.444 3729.66 4192.444 3735.566 4192.434 3735.628 4192.406 3735.684 4192.362 3735.728 4192.306 3735.756 4192.244 3735.766" stroke-width="0" c_etype="pad_outer"/><polygon points="4087.756 3688.864 4087.695 3688.854 4087.64 3688.826 4087.597 3688.783 4087.569 3688.728 4087.559 3688.667 4087.559 3676.856 4087.569 3676.795 4087.597 3676.74 4087.64 3676.697 4087.695 3676.669 4087.756 3676.659 4095.63 3676.659 4095.691 3676.669 4095.746 3676.697 4095.789 3676.74 4095.817 3676.795 4095.827 3676.856 4095.827 3688.667 4095.817 3688.728 4095.789 3688.783 4095.746 3688.826 4095.691 3688.854 4095.63 3688.864" stroke-width="0" c_etype="pad_outer"/><polygon points="4121.535 3688.864 4121.474 3688.854 4121.419 3688.826 4121.376 3688.783 4121.348 3688.728 4121.338 3688.667 4121.338 3676.856 4121.348 3676.795 4121.376 3676.74 4121.419 3676.697 4121.474 3676.669 4121.535 3676.659 4129.409 3676.659 4129.47 3676.669 4129.525 3676.697 4129.568 3676.74 4129.596 3676.795 4129.606 3676.856 4129.606 3688.667 4129.596 3688.728 4129.568 3688.783 4129.525 3688.826 4129.47 3688.854 4129.409 3688.864" stroke-width="0" c_etype="pad_outer"/><polygon points="4118.819 3694.572 4118.758 3694.562 4118.703 3694.534 4118.66 3694.491 4118.632 3694.436 4118.622 3694.375 4118.622 3689.454 4118.632 3689.393 4118.66 3689.338 4118.703 3689.295 4118.758 3689.267 4118.819 3689.257 4120 3689.257 4120.061 3689.267 4120.116 3689.295 4120.159 3689.338 4120.187 3689.393 4120.197 3689.454 4120.197 3694.375 4120.187 3694.436 4120.159 3694.491 4120.116 3694.534 4120.061 3694.562 4120 3694.572" stroke-width="0" c_etype="pad_outer"/><polygon points="4116.85 3694.572 4116.789 3694.562 4116.734 3694.534 4116.691 3694.491 4116.663 3694.436 4116.653 3694.375 4116.653 3689.454 4116.663 3689.393 4116.691 3689.338 4116.734 3689.295 4116.789 3689.267 4116.85 3689.257 4118.032 3689.257 4118.093 3689.267 4118.148 3689.295 4118.191 3689.338 4118.219 3689.393 4118.229 3689.454 4118.229 3694.375 4118.219 3694.436 4118.191 3694.491 4118.148 3694.534 4118.093 3694.562 4118.032 3694.572" stroke-width="0" c_etype="pad_outer"/><polygon points="4114.882 3694.572 4114.821 3694.562 4114.766 3694.534 4114.723 3694.491 4114.695 3694.436 4114.685 3694.375 4114.685 3689.454 4114.695 3689.393 4114.723 3689.338 4114.766 3689.295 4114.821 3689.267 4114.882 3689.257 4116.063 3689.257 4116.124 3689.267 4116.179 3689.295 4116.222 3689.338 4116.25 3689.393 4116.26 3689.454 4116.26 3694.375 4116.25 3694.436 4116.222 3694.491 4116.179 3694.534 4116.124 3694.562 4116.063 3694.572" stroke-width="0" c_etype="pad_outer"/><polygon points="4112.913 3694.572 4112.852 3694.562 4112.797 3694.534 4112.754 3694.491 4112.726 3694.436 4112.716 3694.375 4112.716 3689.454 4112.726 3689.393 4112.754 3689.338 4112.797 3689.295 4112.852 3689.267 4112.913 3689.257 4114.095 3689.257 4114.156 3689.267 4114.211 3689.295 4114.254 3689.338 4114.282 3689.393 4114.292 3689.454 4114.292 3694.375 4114.282 3694.436 4114.254 3694.491 4114.211 3694.534 4114.156 3694.562 4114.095 3694.572" stroke-width="0" c_etype="pad_outer"/><polygon points="4110.945 3694.572 4110.884 3694.562 4110.829 3694.534 4110.786 3694.491 4110.758 3694.436 4110.748 3694.375 4110.748 3689.454 4110.758 3689.393 4110.786 3689.338 4110.829 3689.295 4110.884 3689.267 4110.945 3689.257 4112.126 3689.257 4112.187 3689.267 4112.242 3689.295 4112.285 3689.338 4112.313 3689.393 4112.323 3689.454 4112.323 3694.375 4112.313 3694.436 4112.285 3694.491 4112.242 3694.534 4112.187 3694.562 4112.126 3694.572" stroke-width="0" c_etype="pad_outer"/><polygon points="4108.976 3694.572 4108.915 3694.562 4108.86 3694.534 4108.817 3694.491 4108.789 3694.436 4108.779 3694.375 4108.779 3689.454 4108.789 3689.393 4108.817 3689.338 4108.86 3689.295 4108.915 3689.267 4108.976 3689.257 4110.158 3689.257 4110.219 3689.267 4110.274 3689.295 4110.317 3689.338 4110.345 3689.393 4110.355 3689.454 4110.355 3694.375 4110.345 3694.436 4110.317 3694.491 4110.274 3694.534 4110.219 3694.562 4110.158 3694.572" stroke-width="0" c_etype="pad_outer"/><polygon points="4107.008 3694.572 4106.947 3694.562 4106.892 3694.534 4106.849 3694.491 4106.821 3694.436 4106.811 3694.375 4106.811 3689.454 4106.821 3689.393 4106.849 3689.338 4106.892 3689.295 4106.947 3689.267 4107.008 3689.257 4108.189 3689.257 4108.25 3689.267 4108.305 3689.295 4108.348 3689.338 4108.376 3689.393 4108.386 3689.454 4108.386 3694.375 4108.376 3694.436 4108.348 3694.491 4108.305 3694.534 4108.25 3694.562 4108.189 3694.572" stroke-width="0" c_etype="pad_outer"/><polygon points="4105.039 3694.572 4104.978 3694.562 4104.923 3694.534 4104.88 3694.491 4104.852 3694.436 4104.842 3694.375 4104.842 3689.454 4104.852 3689.393 4104.88 3689.338 4104.923 3689.295 4104.978 3689.267 4105.039 3689.257 4106.221 3689.257 4106.282 3689.267 4106.337 3689.295 4106.38 3689.338 4106.408 3689.393 4106.418 3689.454 4106.418 3694.375 4106.408 3694.436 4106.38 3694.491 4106.337 3694.534 4106.282 3694.562 4106.221 3694.572" stroke-width="0" c_etype="pad_outer"/><polygon points="4103.071 3694.572 4103.01 3694.562 4102.955 3694.534 4102.912 3694.491 4102.884 3694.436 4102.874 3694.375 4102.874 3689.454 4102.884 3689.393 4102.912 3689.338 4102.955 3689.295 4103.01 3689.267 4103.071 3689.257 4104.252 3689.257 4104.313 3689.267 4104.368 3689.295 4104.411 3689.338 4104.439 3689.393 4104.449 3689.454 4104.449 3694.375 4104.439 3694.436 4104.411 3694.491 4104.368 3694.534 4104.313 3694.562 4104.252 3694.572" stroke-width="0" c_etype="pad_outer"/><polygon points="4101.102 3694.572 4101.041 3694.562 4100.986 3694.534 4100.943 3694.491 4100.915 3694.436 4100.905 3694.375 4100.905 3689.454 4100.915 3689.393 4100.943 3689.338 4100.986 3689.295 4101.041 3689.267 4101.102 3689.257 4102.284 3689.257 4102.345 3689.267 4102.4 3689.295 4102.443 3689.338 4102.471 3689.393 4102.481 3689.454 4102.481 3694.375 4102.471 3694.436 4102.443 3694.491 4102.4 3694.534 4102.345 3694.562 4102.284 3694.572" stroke-width="0" c_etype="pad_outer"/><polygon points="4099.134 3694.572 4099.073 3694.562 4099.018 3694.534 4098.975 3694.491 4098.947 3694.436 4098.937 3694.375 4098.937 3689.454 4098.947 3689.393 4098.975 3689.338 4099.018 3689.295 4099.073 3689.267 4099.134 3689.257 4100.315 3689.257 4100.376 3689.267 4100.431 3689.295 4100.474 3689.338 4100.502 3689.393 4100.512 3689.454 4100.512 3694.375 4100.502 3694.436 4100.474 3694.491 4100.431 3694.534 4100.376 3694.562 4100.315 3694.572" stroke-width="0" c_etype="pad_outer"/><polygon points="4097.165 3694.572 4097.104 3694.562 4097.049 3694.534 4097.006 3694.491 4096.978 3694.436 4096.968 3694.375 4096.968 3689.454 4096.978 3689.393 4097.006 3689.338 4097.049 3689.295 4097.104 3689.267 4097.165 3689.257 4098.347 3689.257 4098.408 3689.267 4098.463 3689.295 4098.506 3689.338 4098.534 3689.393 4098.544 3689.454 4098.544 3694.375 4098.534 3694.436 4098.506 3694.491 4098.463 3694.534 4098.408 3694.562 4098.347 3694.572" stroke-width="0" c_etype="pad_outer"/><ellipse cx="4159.173" cy="3600.724" rx="4.137" ry="4.137" stroke-width="0" c_etype="pad_outer"/><ellipse cx="4109.173" cy="3600.724" rx="4.137" ry="4.137" stroke-width="0" c_etype="pad_outer"/><ellipse cx="4027.48" cy="3797.574" rx="2.9559" ry="2.9559" stroke-width="0" c_etype="pad_outer"/><ellipse cx="4067.638" cy="3797.574" rx="2.9559" ry="2.9559" stroke-width="0" c_etype="pad_outer"/><ellipse cx="4086.535" cy="3797.574" rx="2.9559" ry="2.9559" stroke-width="0" c_etype="pad_outer"/><ellipse cx="4126.693" cy="3797.574" rx="2.9559" ry="2.9559" stroke-width="0" c_etype="pad_outer"/><ellipse cx="4145.59" cy="3797.574" rx="2.9559" ry="2.9559" stroke-width="0" c_etype="pad_outer"/><ellipse cx="4185.748" cy="3797.574" rx="2.9559" ry="2.9559" stroke-width="0" c_etype="pad_outer"/><ellipse cx="4027.48" cy="3858.5975" rx="2.9559" ry="2.9559" stroke-width="0" c_etype="pad_outer"/><ellipse cx="4067.638" cy="3858.5975" rx="2.9559" ry="2.9559" stroke-width="0" c_etype="pad_outer"/><ellipse cx="4086.535" cy="3858.5975" rx="2.9559" ry="2.9559" stroke-width="0" c_etype="pad_outer"/><ellipse cx="4126.693" cy="3858.5975" rx="2.9559" ry="2.9559" stroke-width="0" c_etype="pad_outer"/><ellipse cx="4145.59" cy="3858.5975" rx="2.9559" ry="2.9559" stroke-width="0" c_etype="pad_outer"/><ellipse cx="4185.748" cy="3858.5975" rx="2.9559" ry="2.9559" stroke-width="0" c_etype="pad_outer"/><ellipse cx="4094.409" cy="3773.952" rx="2.9559" ry="2.9559" stroke-width="0" c_etype="pad_outer"/><ellipse cx="4134.567" cy="3773.952" rx="2.9559" ry="2.9559" stroke-width="0" c_etype="pad_outer"/><ellipse cx="4149.527" cy="3773.952" rx="2.9559" ry="2.9559" stroke-width="0" c_etype="pad_outer"/><ellipse cx="4189.685" cy="3773.952" rx="2.9559" ry="2.9559" stroke-width="0" c_etype="pad_outer"/><ellipse cx="4149.527" cy="3750.33" rx="2.9559" ry="2.9559" stroke-width="0" c_etype="pad_outer"/><ellipse cx="4189.685" cy="3750.33" rx="2.9559" ry="2.9559" stroke-width="0" c_etype="pad_outer"/><ellipse cx="4149.527" cy="3691.275" rx="2.9559" ry="2.9559" stroke-width="0" c_etype="pad_outer"/><ellipse cx="4189.685" cy="3691.275" rx="2.9559" ry="2.9559" stroke-width="0" c_etype="pad_outer"/><ellipse cx="4149.527" cy="3671.59" rx="2.9559" ry="2.9559" stroke-width="0" c_etype="pad_outer"/><ellipse cx="4189.685" cy="3671.59" rx="2.9559" ry="2.9559" stroke-width="0" c_etype="pad_outer"/><ellipse cx="4031.417" cy="3691.275" rx="2.9559" ry="2.9559" stroke-width="0" c_etype="pad_outer"/><ellipse cx="4071.575" cy="3691.275" rx="2.9559" ry="2.9559" stroke-width="0" c_etype="pad_outer"/><polygon points="4040.039 3847.813 4039.977 3847.803 4039.921 3847.775 4039.877 3847.731 4039.849 3847.675 4039.839 3847.613 4039.839 3840.527 4039.849 3840.465 4039.877 3840.409 4039.921 3840.365 4039.977 3840.337 4040.039 3840.327 4047.126 3840.327 4047.188 3840.337 4047.244 3840.365 4047.288 3840.409 4047.316 3840.465 4047.326 3840.527 4047.326 3847.613 4047.316 3847.675 4047.288 3847.731 4047.244 3847.775 4047.188 3847.803 4047.126 3847.813" stroke-width="0" c_etype="pad_outer"/><ellipse cx="4053.5825" cy="3844.07" rx="3.7433" ry="3.7433" stroke-width="0" c_etype="pad_outer"/><ellipse cx="4063.5825" cy="3844.07" rx="3.7433" ry="3.7433" stroke-width="0" c_etype="pad_outer"/><ellipse cx="4073.5825" cy="3844.07" rx="3.7433" ry="3.7433" stroke-width="0" c_etype="pad_outer"/><ellipse cx="4083.5825" cy="3844.07" rx="3.7433" ry="3.7433" stroke-width="0" c_etype="pad_outer"/><ellipse cx="4093.5825" cy="3844.07" rx="3.7433" ry="3.7433" stroke-width="0" c_etype="pad_outer"/><ellipse cx="4103.5825" cy="3844.07" rx="3.7433" ry="3.7433" stroke-width="0" c_etype="pad_outer"/><ellipse cx="4113.5825" cy="3844.07" rx="3.7433" ry="3.7433" stroke-width="0" c_etype="pad_outer"/><ellipse cx="4123.5825" cy="3844.07" rx="3.7433" ry="3.7433" stroke-width="0" c_etype="pad_outer"/><ellipse cx="4133.5825" cy="3844.07" rx="3.7433" ry="3.7433" stroke-width="0" c_etype="pad_outer"/><ellipse cx="4143.5825" cy="3844.07" rx="3.7433" ry="3.7433" stroke-width="0" c_etype="pad_outer"/><ellipse cx="4153.5825" cy="3844.07" rx="3.7433" ry="3.7433" stroke-width="0" c_etype="pad_outer"/><ellipse cx="4163.5825" cy="3844.07" rx="3.7433" ry="3.7433" stroke-width="0" c_etype="pad_outer"/><ellipse cx="4173.5825" cy="3844.07" rx="3.7433" ry="3.7433" stroke-width="0" c_etype="pad_outer"/><ellipse cx="4173.5825" cy="3814.07" rx="3.7433" ry="3.7433" stroke-width="0" c_etype="pad_outer"/><ellipse cx="4163.5825" cy="3814.07" rx="3.7433" ry="3.7433" stroke-width="0" c_etype="pad_outer"/><ellipse cx="4153.5825" cy="3814.07" rx="3.7433" ry="3.7433" stroke-width="0" c_etype="pad_outer"/><ellipse cx="4143.5825" cy="3814.07" rx="3.7433" ry="3.7433" stroke-width="0" c_etype="pad_outer"/><ellipse cx="4133.5825" cy="3814.07" rx="3.7433" ry="3.7433" stroke-width="0" c_etype="pad_outer"/><ellipse cx="4123.5825" cy="3814.07" rx="3.7433" ry="3.7433" stroke-width="0" c_etype="pad_outer"/><ellipse cx="4113.5825" cy="3814.07" rx="3.7433" ry="3.7433" stroke-width="0" c_etype="pad_outer"/><ellipse cx="4103.5825" cy="3814.07" rx="3.7433" ry="3.7433" stroke-width="0" c_etype="pad_outer"/><ellipse cx="4093.5825" cy="3814.07" rx="3.7433" ry="3.7433" stroke-width="0" c_etype="pad_outer"/><ellipse cx="4083.5825" cy="3814.07" rx="3.7433" ry="3.7433" stroke-width="0" c_etype="pad_outer"/><ellipse cx="4073.5825" cy="3814.07" rx="3.7433" ry="3.7433" stroke-width="0" c_etype="pad_outer"/><ellipse cx="4063.5825" cy="3814.07" rx="3.7433" ry="3.7433" stroke-width="0" c_etype="pad_outer"/><ellipse cx="4053.5825" cy="3814.07" rx="3.7433" ry="3.7433" stroke-width="0" c_etype="pad_outer"/><ellipse cx="4043.5825" cy="3814.07" rx="3.7433" ry="3.7433" stroke-width="0" c_etype="pad_outer"/></g></mask><mask id="topSignalSolderMask" maskUnits="userSpaceOnUse" x="4020" y="3396" width="177.2" height="472.4"><path d="M4035.7493 3868.44,4035.3938 3868.4359,4035.3881 3868.4357,4035.0416 3868.4241,4035.036 3868.4238,4034.6849 3868.404,4034.6794 3868.4036,4034.3336 3868.3762,4034.328 3868.3757,4033.9828 3868.3407,4033.9771 3868.3401,4033.6243 3868.2961,4033.6186 3868.2953,4033.2793 3868.2451,4033.2739 3868.2443,4032.9234 3868.1846,4032.9178 3868.1835,4032.5809 3868.1181,4032.5754 3868.117,4032.2322 3868.0425,4032.2267 3868.0412,4031.8857 3867.959,4031.8801 3867.9576,4031.5416 3867.8677,4031.5363 3867.8662,4031.2031 3867.7699,4031.1976 3867.7682,4030.8647 3867.6636,4030.8595 3867.6619,4030.5274 3867.5494,4030.522 3867.5475,4030.1925 3867.4275,4030.1871 3867.4255,4029.8629 3867.2989,4029.8577 3867.2968,4029.538 3867.1638,4029.5328 3867.1616,4029.2094 3867.0183,4029.2043 3867.0159,4028.8911 3866.8688,4028.8861 3866.8663,4028.5712 3866.7096,4028.566 3866.707,4028.2579 3866.5447,4028.2531 3866.542,4027.9474 3866.3722,4027.9425 3866.3695,4027.6422 3866.1938,4027.6373 3866.1908,4027.3381 3866.0063,4027.3333 3866.0033,4027.0435 3865.8155,4027.039 3865.8125,4026.745 3865.6127,4026.7403 3865.6094,4026.4594 3865.409,4026.4549 3865.4057,4026.1728 3865.1946,4026.1683 3865.1912,4025.8984 3864.9796,4025.894 3864.976,4025.6166 3864.7482,4025.6123 3864.7446,4025.3533 3864.522,4025.3491 3864.5183,4025.0882 3864.2837,4025.084 3864.2799,4024.8293 3864.0401,4024.8253 3864.0363,4024.5751 3863.79,4024.571 3863.7859,4024.3292 3863.5367,4024.3253 3863.5327,4024.0889 3863.278,4024.0852 3863.2739,4023.8503 3863.009,4023.8466 3863.0048,4023.6243 3862.7426,4023.6206 3862.7383,4023.3976 3862.4627,4023.3942 3862.4582,4023.1824 3862.1844,4023.179 3862.1799,4022.9715 3861.8984,4022.9683 3861.8939,4022.7651 3861.605,4022.7619 3861.6004,4022.569 3861.3125,4022.5659 3861.3078,4022.3796 3861.0159,4022.3765 3861.011,4022.195 3860.7116,4022.1922 3860.7068,4022.0156 3860.4005,4022.0128 3860.3955,4021.8473 3860.0927,4021.8447 3860.0877,4021.6827 3859.7749,4021.6802 3859.7699,4021.5282 3859.4593,4021.5258 3859.4542,4021.3762 3859.1301,4021.3739 3859.125,4021.2371 3858.8105,4021.2348 3858.8052,4021.1025 3858.4807,4021.1005 3858.4755,4020.9772 3858.153,4020.9752 3858.1477,4020.8556 3857.8123,4020.8537 3857.8069,4020.7462 3857.4821,4020.7446 3857.4768,4020.6401 3857.1361,4020.6385 3857.1307,4020.5453 3856.8,4020.5438 3856.7945,4020.4554 3856.4514,4020.4541 3856.446,4020.3751 3856.1089,4020.3738 3856.1033,4020.3021 3855.7617,4020.301 3855.7562,4020.2363 3855.4102,4020.2354 3855.4046,4020.1794 3855.0624,4020.1785 3855.0568,4020.1302 3854.7123,4020.1294 3854.7067,4020.0885 3854.3589,4020.0879 3854.3533,4020.0547 3854.0033,4020.0543 3853.9977,4020.0291 3853.6509,4020.0288 3853.6451,4020.0115 3853.2947,4020.0113 3853.2891,4020.002 3852.9426,4020.0019 3852.9377,4019.9999 3852.691,4020 3852.689,4020 3411.7504,4019.9999 3411.7476,4020.004 3411.3938,4020.0042 3411.3881,4020.0158 3411.0416,4020.0161 3411.036,4020.0359 3410.6849,4020.0363 3410.6794,4020.0637 3410.3336,4020.0642 3410.328,4020.0992 3409.9828,4020.0998 3409.9771,4020.1438 3409.6243,4020.1446 3409.6186,4020.1948 3409.2793,4020.1956 3409.2739,4020.2553 3408.9234,4020.2564 3408.9178,4020.3218 3408.5809,4020.3229 3408.5754,4020.3974 3408.2322,4020.3987 3408.2267,4020.4809 3407.8857,4020.4823 3407.8801,4020.5722 3407.5416,4020.5737 3407.5363,4020.67 3407.2031,4020.6717 3407.1976,4020.7763 3406.8647,4020.778 3406.8595,4020.8905 3406.5274,4020.8924 3406.522,4021.0124 3406.1925,4021.0144 3406.1871,4021.141 3405.8629,4021.1431 3405.8577,4021.2761 3405.538,4021.2783 3405.5328,4021.4216 3405.2094,4021.424 3405.2043,4021.5711 3404.8911,4021.5736 3404.8861,4021.7303 3404.5712,4021.7329 3404.566,4021.8952 3404.2579,4021.8979 3404.2531,4022.0677 3403.9474,4022.0704 3403.9425,4022.2461 3403.6422,4022.2491 3403.6373,4022.4336 3403.3381,4022.4366 3403.3333,4022.6244 3403.0435,4022.6274 3403.039,4022.8272 3402.745,4022.8305 3402.7403,4023.0309 3402.4594,4023.0342 3402.4549,4023.2453 3402.1728,4023.2487 3402.1683,4023.4593 3401.8996,4023.4628 3401.8952,4023.6917 3401.6165,4023.6953 3401.6123,4023.9179 3401.3533,4023.9216 3401.3491,4024.1562 3401.0882,4024.16 3401.084,4024.3998 3400.8293,4024.4036 3400.8253,4024.6499 3400.5751,4024.654 3400.571,4024.9032 3400.3292,4024.9072 3400.3253,4025.1619 3400.0889,4025.166 3400.0852,4025.4309 3399.8503,4025.4351 3399.8466,4025.6973 3399.6243,4025.7016 3399.6206,4025.9772 3399.3976,4025.9817 3399.3942,4026.2555 3399.1824,4026.26 3399.179,4026.5415 3398.9715,4026.546 3398.9683,4026.8349 3398.7651,4026.8395 3398.7619,4027.1274 3398.569,4027.1321 3398.5659,4027.424 3398.3796,4027.4289 3398.3765,4027.7283 3398.195,4027.7331 3398.1922,4028.0394 3398.0156,4028.0444 3398.0128,4028.3472 3397.8473,4028.3522 3397.8447,4028.665 3397.6827,4028.67 3397.6802,4028.9806 3397.5282,4028.9857 3397.5257,4029.309 3397.3765,4029.314 3397.3743,4029.6293 3397.2371,4029.6347 3397.2348,4029.9592 3397.1025,4029.9644 3397.1005,4030.2869 3396.9772,4030.2922 3396.9752,4030.6276 3396.8556,4030.633 3396.8537,4030.9578 3396.7462,4030.9631 3396.7446,4031.3038 3396.6401,4031.3092 3396.6385,4031.6399 3396.5453,4031.6454 3396.5438,4031.9885 3396.4554,4031.9939 3396.4541,4032.331 3396.3751,4032.3366 3396.3738,4032.6782 3396.3021,4032.6837 3396.301,4033.0297 3396.2363,4033.0353 3396.2354,4033.3775 3396.1794,4033.3831 3396.1785,4033.7276 3396.1302,4033.7332 3396.1294,4034.081 3396.0885,4034.0866 3396.0879,4034.4366 3396.0547,4034.4422 3396.0543,4034.789 3396.0291,4034.7948 3396.0288,4035.1452 3396.0115,4035.1508 3396.0113,4035.4973 3396.002,4035.5022 3396.0019,4035.7489 3395.9999,4035.7509 3396,4181.4128 3396,4181.4156 3395.9999,4181.7711 3396.004,4181.7768 3396.0042,4182.1233 3396.0158,4182.1289 3396.0161,4182.48 3396.0359,4182.4855 3396.0363,4182.8313 3396.0637,4182.8369 3396.0642,4183.1821 3396.0992,4183.1878 3396.0998,4183.5406 3396.1438,4183.5463 3396.1446,4183.8856 3396.1948,4183.891 3396.1956,4184.2415 3396.2553,4184.2471 3396.2564,4184.584 3396.3218,4184.5895 3396.3229,4184.9327 3396.3974,4184.9382 3396.3987,4185.2792 3396.4809,4185.2848 3396.4823,4185.6233 3396.5722,4185.6286 3396.5737,4185.9618 3396.67,4185.9673 3396.6717,4186.3002 3396.7763,4186.3054 3396.778,4186.6375 3396.8905,4186.6429 3396.8924,4186.9724 3397.0124,4186.9778 3397.0144,4187.302 3397.141,4187.3072 3397.1431,4187.6269 3397.2761,4187.6321 3397.2783,4187.9555 3397.4216,4187.9606 3397.424,4188.2738 3397.5711,4188.2788 3397.5736,4188.5937 3397.7303,4188.5989 3397.7329,4188.907 3397.8952,4188.9118 3397.8979,4189.2175 3398.0677,4189.2224 3398.0704,4189.5227 3398.2461,4189.5276 3398.2491,4189.8268 3398.4336,4189.8316 3398.4366,4190.1214 3398.6244,4190.1259 3398.6274,4190.4199 3398.8272,4190.4246 3398.8305,4190.7055 3399.0309,4190.71 3399.0342,4190.9921 3399.2453,4190.9966 3399.2487,4191.2665 3399.4603,4191.2709 3399.4639,4191.5483 3399.6917,4191.5526 3399.6953,4191.8116 3399.9179,4191.8158 3399.9216,4192.0767 3400.1562,4192.0809 3400.16,4192.3356 3400.3998,4192.3396 3400.4036,4192.5898 3400.6499,4192.5939 3400.654,4192.8357 3400.9032,4192.8396 3400.9072,4193.076 3401.1619,4193.0797 3401.166,4193.3146 3401.4309,4193.3183 3401.4351,4193.5406 3401.6973,4193.5443 3401.7016,4193.7673 3401.9772,4193.7707 3401.9817,4193.9825 3402.2555,4193.9859 3402.26,4194.1924 3402.5401,4194.1956 3402.5446,4194.3998 3402.8349,4194.403 3402.8395,4194.5959 3403.1274,4194.599 3403.1321,4194.7853 3403.424,4194.7884 3403.4289,4194.9699 3403.7283,4194.9727 3403.7331,4195.1493 3404.0394,4195.1521 3404.0444,4195.3176 3404.3472,4195.3202 3404.3522,4195.4822 3404.665,4195.4847 3404.67,4195.6367 3404.9806,4195.6391 3404.9857,4195.7887 3405.3098,4195.791 3405.3149,4195.9278 3405.6294,4195.9301 3405.6347,4196.0624 3405.9592,4196.0644 3405.9644,4196.1877 3406.2869,4196.1897 3406.2922,4196.3093 3406.6276,4196.3111 3406.6329,4196.4181 3406.9559,4196.4199 3406.9613,4196.5249 3407.3038,4196.5264 3407.3092,4196.6196 3407.6399,4196.6211 3407.6454,4196.7095 3407.9885,4196.7108 3407.9939,4196.7898 3408.331,4196.7911 3408.3366,4196.8628 3408.6782,4196.8639 3408.6837,4196.9286 3409.0297,4196.9295 3409.0353,4196.9855 3409.3775,4196.9864 3409.3831,4197.0347 3409.7276,4197.0355 3409.7332,4197.0764 3410.081,4197.077 3410.0866,4197.1102 3410.4366,4197.1106 3410.4422,4197.1358 3410.789,4197.1361 3410.7948,4197.1534 3411.1452,4197.1536 3411.1508,4197.1629 3411.4973,4197.163 3411.5021,4197.165 3411.7449,4197.165 3852.6906,4197.1609 3853.0461,4197.1607 3853.0518,4197.1491 3853.3983,4197.1488 3853.4039,4197.129 3853.755,4197.1286 3853.7605,4197.1012 3854.1063,4197.1007 3854.1119,4197.0657 3854.4571,4197.0651 3854.4628,4197.0211 3854.8156,4197.0203 3854.8213,4196.9701 3855.1606,4196.9693 3855.166,4196.9096 3855.5165,4196.9085 3855.5221,4196.8431 3855.859,4196.842 3855.8645,4196.7675 3856.2077,4196.7662 3856.2132,4196.684 3856.5542,4196.6826 3856.5598,4196.5927 3856.8983,4196.5912 3856.9036,4196.4949 3857.2368,4196.4932 3857.2423,4196.3886 3857.5752,4196.3869 3857.5804,4196.2744 3857.9125,4196.2725 3857.9179,4196.1525 3858.2474,4196.1505 3858.2528,4196.0239 3858.577,4196.0218 3858.5822,4195.8888 3858.9019,4195.8866 3858.9071,4195.7433 3859.2305,4195.7409 3859.2356,4195.5938 3859.5488,4195.5913 3859.5538,4195.4346 3859.8687,4195.432 3859.8739,4195.2697 3860.182,4195.267 3860.1868,4195.0972 3860.4925,4195.0945 3860.4974,4194.9188 3860.7977,4194.9158 3860.8026,4194.7313 3861.1018,4194.7283 3861.1066,4194.5405 3861.3964,4194.5375 3861.4009,4194.3377 3861.6949,4194.3344 3861.6996,4194.134 3861.9805,4194.1307 3861.985,4193.9196 3862.2671,4193.9162 3862.2716,4193.7056 3862.5403,4193.7021 3862.5447,4193.4736 3862.8229,4193.47 3862.8271,4193.247 3863.0866,4193.2433 3863.0908,4193.0087 3863.3517,4193.0049 3863.3559,4192.7651 3863.6106,4192.7613 3863.6146,4192.515 3863.8648,4192.5109 3863.8689,4192.2617 3864.1107,4192.2577 3864.1146,4192.003 3864.351,4191.9989 3864.3547,4191.734 3864.5896,4191.7298 3864.5933,4191.4676 3864.8156,4191.4633 3864.8193,4191.1877 3865.0423,4191.1832 3865.0457,4190.9094 3865.2575,4190.9049 3865.2609,4190.6234 3865.4684,4190.6189 3865.4716,4190.33 3865.6748,4190.3254 3865.678,4190.0375 3865.8709,4190.0328 3865.874,4189.7409 3866.0603,4189.736 3866.0634,4189.4366 3866.2449,4189.4318 3866.2477,4189.1255 3866.4243,4189.1205 3866.4271,4188.8177 3866.5926,4188.8127 3866.5952,4188.4999 3866.7572,4188.4949 3866.7597,4188.1843 3866.9117,4188.1792 3866.9142,4187.8559 3867.0634,4187.8509 3867.0656,4187.5356 3867.2028,4187.5302 3867.2051,4187.2057 3867.3374,4187.2005 3867.3394,4186.878 3867.4627,4186.8727 3867.4647,4186.5373 3867.5843,4186.5319 3867.5862,4186.2071 3867.6937,4186.2018 3867.6953,4185.8611 3867.7998,4185.8557 3867.8014,4185.525 3867.8946,4185.5195 3867.8961,4185.1764 3867.9845,4185.171 3867.9858,4184.8339 3868.0648,4184.8283 3868.0661,4184.4867 3868.1378,4184.4812 3868.1389,4184.1352 3868.2036,4184.1296 3868.2045,4183.7874 3868.2605,4183.7818 3868.2614,4183.4373 3868.3097,4183.4317 3868.3105,4183.0839 3868.3514,4183.0783 3868.352,4182.7283 3868.3852,4182.7227 3868.3856,4182.3759 3868.4108,4182.3701 3868.4111,4182.0197 3868.4284,4182.0141 3868.4286,4181.6676 3868.4379,4181.6627 3868.438,4181.416 3868.44z" stroke="none" fill="white"/><g fill="black"><polygon points="4056.417 3716.082 4056.355 3716.072 4056.299 3716.044 4056.255 3716 4056.227 3715.944 4056.217 3715.882 4056.217 3709.976 4056.227 3709.914 4056.255 3709.858 4056.299 3709.814 4056.355 3709.786 4056.417 3709.776 4062.323 3709.776 4062.385 3709.786 4062.441 3709.814 4062.485 3709.858 4062.513 3709.914 4062.523 3709.976 4062.523 3715.882 4062.513 3715.944 4062.485 3716 4062.441 3716.044 4062.385 3716.072 4062.323 3716.082" stroke-width="0" c_etype="pad_outer"/><polygon points="4080.039 3716.082 4079.977 3716.072 4079.921 3716.044 4079.877 3716 4079.849 3715.944 4079.839 3715.882 4079.839 3709.976 4079.849 3709.914 4079.877 3709.858 4079.921 3709.814 4079.977 3709.786 4080.039 3709.776 4085.945 3709.776 4086.007 3709.786 4086.063 3709.814 4086.107 3709.858 4086.135 3709.914 4086.145 3709.976 4086.145 3715.882 4086.135 3715.944 4086.107 3716 4086.063 3716.044 4086.007 3716.072 4085.945 3716.082" stroke-width="0" c_etype="pad_outer"/><polygon points="4056.417 3727.892 4056.355 3727.882 4056.299 3727.854 4056.255 3727.81 4056.227 3727.754 4056.217 3727.692 4056.217 3721.786 4056.227 3721.724 4056.255 3721.668 4056.299 3721.624 4056.355 3721.596 4056.417 3721.586 4062.323 3721.586 4062.385 3721.596 4062.441 3721.624 4062.485 3721.668 4062.513 3721.724 4062.523 3721.786 4062.523 3727.692 4062.513 3727.754 4062.485 3727.81 4062.441 3727.854 4062.385 3727.882 4062.323 3727.892" stroke-width="0" c_etype="pad_outer"/><polygon points="4080.039 3727.892 4079.977 3727.882 4079.921 3727.854 4079.877 3727.81 4079.849 3727.754 4079.839 3727.692 4079.839 3721.786 4079.849 3721.724 4079.877 3721.668 4079.921 3721.624 4079.977 3721.596 4080.039 3721.586 4085.945 3721.586 4086.007 3721.596 4086.063 3721.624 4086.107 3721.668 4086.135 3721.724 4086.145 3721.786 4086.145 3727.692 4086.135 3727.754 4086.107 3727.81 4086.063 3727.854 4086.007 3727.882 4085.945 3727.892" stroke-width="0" c_etype="pad_outer"/><polygon points="4083.976 3743.641 4083.914 3743.631 4083.858 3743.603 4083.814 3743.559 4083.786 3743.503 4083.776 3743.441 4083.776 3737.535 4083.786 3737.473 4083.814 3737.417 4083.858 3737.373 4083.914 3737.345 4083.976 3737.335 4089.882 3737.335 4089.944 3737.345 4090 3737.373 4090.044 3737.417 4090.072 3737.473 4090.082 3737.535 4090.082 3743.441 4090.072 3743.503 4090.044 3743.559 4090 3743.603 4089.944 3743.631 4089.882 3743.641" stroke-width="0" c_etype="pad_outer"/><polygon points="4107.598 3743.641 4107.536 3743.631 4107.48 3743.603 4107.436 3743.559 4107.408 3743.503 4107.398 3743.441 4107.398 3737.535 4107.408 3737.473 4107.436 3737.417 4107.48 3737.373 4107.536 3737.345 4107.598 3737.335 4113.504 3737.335 4113.566 3737.345 4113.622 3737.373 4113.666 3737.417 4113.694 3737.473 4113.704 3737.535 4113.704 3743.441 4113.694 3743.503 4113.666 3743.559 4113.622 3743.603 4113.566 3743.631 4113.504 3743.641" stroke-width="0" c_etype="pad_outer"/><polygon points="4083.976 3755.451 4083.914 3755.441 4083.858 3755.413 4083.814 3755.369 4083.786 3755.313 4083.776 3755.251 4083.776 3749.345 4083.786 3749.283 4083.814 3749.227 4083.858 3749.183 4083.914 3749.155 4083.976 3749.145 4089.882 3749.145 4089.944 3749.155 4090 3749.183 4090.044 3749.227 4090.072 3749.283 4090.082 3749.345 4090.082 3755.251 4090.072 3755.313 4090.044 3755.369 4090 3755.413 4089.944 3755.441 4089.882 3755.451" stroke-width="0" c_etype="pad_outer"/><polygon points="4107.598 3755.451 4107.536 3755.441 4107.48 3755.413 4107.436 3755.369 4107.408 3755.313 4107.398 3755.251 4107.398 3749.345 4107.408 3749.283 4107.436 3749.227 4107.48 3749.183 4107.536 3749.155 4107.598 3749.145 4113.504 3749.145 4113.566 3749.155 4113.622 3749.183 4113.666 3749.227 4113.694 3749.283 4113.704 3749.345 4113.704 3755.251 4113.694 3755.313 4113.666 3755.369 4113.622 3755.413 4113.566 3755.441 4113.504 3755.451" stroke-width="0" c_etype="pad_outer"/><polygon points="4028.858 3743.641 4028.796 3743.631 4028.74 3743.603 4028.696 3743.559 4028.668 3743.503 4028.658 3743.441 4028.658 3737.535 4028.668 3737.473 4028.696 3737.417 4028.74 3737.373 4028.796 3737.345 4028.858 3737.335 4034.764 3737.335 4034.826 3737.345 4034.882 3737.373 4034.926 3737.417 4034.954 3737.473 4034.964 3737.535 4034.964 3743.441 4034.954 3743.503 4034.926 3743.559 4034.882 3743.603 4034.826 3743.631 4034.764 3743.641" stroke-width="0" c_etype="pad_outer"/><polygon points="4052.48 3743.641 4052.418 3743.631 4052.362 3743.603 4052.318 3743.559 4052.29 3743.503 4052.28 3743.441 4052.28 3737.535 4052.29 3737.473 4052.318 3737.417 4052.362 3737.373 4052.418 3737.345 4052.48 3737.335 4058.386 3737.335 4058.448 3737.345 4058.504 3737.373 4058.548 3737.417 4058.576 3737.473 4058.586 3737.535 4058.586 3743.441 4058.576 3743.503 4058.548 3743.559 4058.504 3743.603 4058.448 3743.631 4058.386 3743.641" stroke-width="0" c_etype="pad_outer"/><polygon points="4028.858 3755.451 4028.796 3755.441 4028.74 3755.413 4028.696 3755.369 4028.668 3755.313 4028.658 3755.251 4028.658 3749.345 4028.668 3749.283 4028.696 3749.227 4028.74 3749.183 4028.796 3749.155 4028.858 3749.145 4034.764 3749.145 4034.826 3749.155 4034.882 3749.183 4034.926 3749.227 4034.954 3749.283 4034.964 3749.345 4034.964 3755.251 4034.954 3755.313 4034.926 3755.369 4034.882 3755.413 4034.826 3755.441 4034.764 3755.451" stroke-width="0" c_etype="pad_outer"/><polygon points="4052.48 3755.451 4052.418 3755.441 4052.362 3755.413 4052.318 3755.369 4052.29 3755.313 4052.28 3755.251 4052.28 3749.345 4052.29 3749.283 4052.318 3749.227 4052.362 3749.183 4052.418 3749.155 4052.48 3749.145 4058.386 3749.145 4058.448 3749.155 4058.504 3749.183 4058.548 3749.227 4058.576 3749.283 4058.586 3749.345 4058.586 3755.251 4058.576 3755.313 4058.548 3755.369 4058.504 3755.413 4058.448 3755.441 4058.386 3755.451" stroke-width="0" c_etype="pad_outer"/><polygon points="4056.417 3771.2 4056.355 3771.19 4056.299 3771.162 4056.255 3771.118 4056.227 3771.062 4056.217 3771 4056.217 3765.094 4056.227 3765.032 4056.255 3764.976 4056.299 3764.932 4056.355 3764.904 4056.417 3764.894 4062.323 3764.894 4062.385 3764.904 4062.441 3764.932 4062.485 3764.976 4062.513 3765.032 4062.523 3765.094 4062.523 3771 4062.513 3771.062 4062.485 3771.118 4062.441 3771.162 4062.385 3771.19 4062.323 3771.2" stroke-width="0" c_etype="pad_outer"/><polygon points="4080.039 3771.2 4079.977 3771.19 4079.921 3771.162 4079.877 3771.118 4079.849 3771.062 4079.839 3771 4079.839 3765.094 4079.849 3765.032 4079.877 3764.976 4079.921 3764.932 4079.977 3764.904 4080.039 3764.894 4085.945 3764.894 4086.007 3764.904 4086.063 3764.932 4086.107 3764.976 4086.135 3765.032 4086.145 3765.094 4086.145 3771 4086.135 3771.062 4086.107 3771.118 4086.063 3771.162 4086.007 3771.19 4085.945 3771.2" stroke-width="0" c_etype="pad_outer"/><polygon points="4056.417 3783.01 4056.355 3783 4056.299 3782.972 4056.255 3782.928 4056.227 3782.872 4056.217 3782.81 4056.217 3776.904 4056.227 3776.842 4056.255 3776.786 4056.299 3776.742 4056.355 3776.714 4056.417 3776.704 4062.323 3776.704 4062.385 3776.714 4062.441 3776.742 4062.485 3776.786 4062.513 3776.842 4062.523 3776.904 4062.523 3782.81 4062.513 3782.872 4062.485 3782.928 4062.441 3782.972 4062.385 3783 4062.323 3783.01" stroke-width="0" c_etype="pad_outer"/><polygon points="4080.039 3783.01 4079.977 3783 4079.921 3782.972 4079.877 3782.928 4079.849 3782.872 4079.839 3782.81 4079.839 3776.904 4079.849 3776.842 4079.877 3776.786 4079.921 3776.742 4079.977 3776.714 4080.039 3776.704 4085.945 3776.704 4086.007 3776.714 4086.063 3776.742 4086.107 3776.786 4086.135 3776.842 4086.145 3776.904 4086.145 3782.81 4086.135 3782.872 4086.107 3782.928 4086.063 3782.972 4086.007 3783 4085.945 3783.01" stroke-width="0" c_etype="pad_outer"/><polygon points="4123.346 3723.956 4123.284 3723.946 4123.228 3723.918 4123.184 3723.874 4123.156 3723.818 4123.146 3723.756 4123.146 3717.85 4123.156 3717.788 4123.184 3717.732 4123.228 3717.688 4123.284 3717.66 4123.346 3717.65 4129.252 3717.65 4129.314 3717.66 4129.37 3717.688 4129.414 3717.732 4129.442 3717.788 4129.452 3717.85 4129.452 3723.756 4129.442 3723.818 4129.414 3723.874 4129.37 3723.918 4129.314 3723.946 4129.252 3723.956" stroke-width="0" c_etype="pad_outer"/><polygon points="4146.968 3723.956 4146.906 3723.946 4146.85 3723.918 4146.806 3723.874 4146.778 3723.818 4146.768 3723.756 4146.768 3717.85 4146.778 3717.788 4146.806 3717.732 4146.85 3717.688 4146.906 3717.66 4146.968 3717.65 4152.874 3717.65 4152.936 3717.66 4152.992 3717.688 4153.036 3717.732 4153.064 3717.788 4153.074 3717.85 4153.074 3723.756 4153.064 3723.818 4153.036 3723.874 4152.992 3723.918 4152.936 3723.946 4152.874 3723.956" stroke-width="0" c_etype="pad_outer"/><polygon points="4123.346 3735.766 4123.284 3735.756 4123.228 3735.728 4123.184 3735.684 4123.156 3735.628 4123.146 3735.566 4123.146 3729.66 4123.156 3729.598 4123.184 3729.542 4123.228 3729.498 4123.284 3729.47 4123.346 3729.46 4129.252 3729.46 4129.314 3729.47 4129.37 3729.498 4129.414 3729.542 4129.442 3729.598 4129.452 3729.66 4129.452 3735.566 4129.442 3735.628 4129.414 3735.684 4129.37 3735.728 4129.314 3735.756 4129.252 3735.766" stroke-width="0" c_etype="pad_outer"/><polygon points="4146.968 3735.766 4146.906 3735.756 4146.85 3735.728 4146.806 3735.684 4146.778 3735.628 4146.768 3735.566 4146.768 3729.66 4146.778 3729.598 4146.806 3729.542 4146.85 3729.498 4146.906 3729.47 4146.968 3729.46 4152.874 3729.46 4152.936 3729.47 4152.992 3729.498 4153.036 3729.542 4153.064 3729.598 4153.074 3729.66 4153.074 3735.566 4153.064 3735.628 4153.036 3735.684 4152.992 3735.728 4152.936 3735.756 4152.874 3735.766" stroke-width="0" c_etype="pad_outer"/><polygon points="4162.716 3723.956 4162.654 3723.946 4162.598 3723.918 4162.554 3723.874 4162.526 3723.818 4162.516 3723.756 4162.516 3717.85 4162.526 3717.788 4162.554 3717.732 4162.598 3717.688 4162.654 3717.66 4162.716 3717.65 4168.622 3717.65 4168.684 3717.66 4168.74 3717.688 4168.784 3717.732 4168.812 3717.788 4168.822 3717.85 4168.822 3723.756 4168.812 3723.818 4168.784 3723.874 4168.74 3723.918 4168.684 3723.946 4168.622 3723.956" stroke-width="0" c_etype="pad_outer"/><polygon points="4186.338 3723.956 4186.276 3723.946 4186.22 3723.918 4186.176 3723.874 4186.148 3723.818 4186.138 3723.756 4186.138 3717.85 4186.148 3717.788 4186.176 3717.732 4186.22 3717.688 4186.276 3717.66 4186.338 3717.65 4192.244 3717.65 4192.306 3717.66 4192.362 3717.688 4192.406 3717.732 4192.434 3717.788 4192.444 3717.85 4192.444 3723.756 4192.434 3723.818 4192.406 3723.874 4192.362 3723.918 4192.306 3723.946 4192.244 3723.956" stroke-width="0" c_etype="pad_outer"/><polygon points="4162.716 3735.766 4162.654 3735.756 4162.598 3735.728 4162.554 3735.684 4162.526 3735.628 4162.516 3735.566 4162.516 3729.66 4162.526 3729.598 4162.554 3729.542 4162.598 3729.498 4162.654 3729.47 4162.716 3729.46 4168.622 3729.46 4168.684 3729.47 4168.74 3729.498 4168.784 3729.542 4168.812 3729.598 4168.822 3729.66 4168.822 3735.566 4168.812 3735.628 4168.784 3735.684 4168.74 3735.728 4168.684 3735.756 4168.622 3735.766" stroke-width="0" c_etype="pad_outer"/><polygon points="4186.338 3735.766 4186.276 3735.756 4186.22 3735.728 4186.176 3735.684 4186.148 3735.628 4186.138 3735.566 4186.138 3729.66 4186.148 3729.598 4186.176 3729.542 4186.22 3729.498 4186.276 3729.47 4186.338 3729.46 4192.244 3729.46 4192.306 3729.47 4192.362 3729.498 4192.406 3729.542 4192.434 3729.598 4192.444 3729.66 4192.444 3735.566 4192.434 3735.628 4192.406 3735.684 4192.362 3735.728 4192.306 3735.756 4192.244 3735.766" stroke-width="0" c_etype="pad_outer"/><polygon points="4087.756 3688.864 4087.695 3688.854 4087.64 3688.826 4087.597 3688.783 4087.569 3688.728 4087.559 3688.667 4087.559 3676.856 4087.569 3676.795 4087.597 3676.74 4087.64 3676.697 4087.695 3676.669 4087.756 3676.659 4095.63 3676.659 4095.691 3676.669 4095.746 3676.697 4095.789 3676.74 4095.817 3676.795 4095.827 3676.856 4095.827 3688.667 4095.817 3688.728 4095.789 3688.783 4095.746 3688.826 4095.691 3688.854 4095.63 3688.864" stroke-width="0" c_etype="pad_outer"/><polygon points="4121.535 3688.864 4121.474 3688.854 4121.419 3688.826 4121.376 3688.783 4121.348 3688.728 4121.338 3688.667 4121.338 3676.856 4121.348 3676.795 4121.376 3676.74 4121.419 3676.697 4121.474 3676.669 4121.535 3676.659 4129.409 3676.659 4129.47 3676.669 4129.525 3676.697 4129.568 3676.74 4129.596 3676.795 4129.606 3676.856 4129.606 3688.667 4129.596 3688.728 4129.568 3688.783 4129.525 3688.826 4129.47 3688.854 4129.409 3688.864" stroke-width="0" c_etype="pad_outer"/><polygon points="4118.819 3694.572 4118.758 3694.562 4118.703 3694.534 4118.66 3694.491 4118.632 3694.436 4118.622 3694.375 4118.622 3689.454 4118.632 3689.393 4118.66 3689.338 4118.703 3689.295 4118.758 3689.267 4118.819 3689.257 4120 3689.257 4120.061 3689.267 4120.116 3689.295 4120.159 3689.338 4120.187 3689.393 4120.197 3689.454 4120.197 3694.375 4120.187 3694.436 4120.159 3694.491 4120.116 3694.534 4120.061 3694.562 4120 3694.572" stroke-width="0" c_etype="pad_outer"/><polygon points="4116.85 3694.572 4116.789 3694.562 4116.734 3694.534 4116.691 3694.491 4116.663 3694.436 4116.653 3694.375 4116.653 3689.454 4116.663 3689.393 4116.691 3689.338 4116.734 3689.295 4116.789 3689.267 4116.85 3689.257 4118.032 3689.257 4118.093 3689.267 4118.148 3689.295 4118.191 3689.338 4118.219 3689.393 4118.229 3689.454 4118.229 3694.375 4118.219 3694.436 4118.191 3694.491 4118.148 3694.534 4118.093 3694.562 4118.032 3694.572" stroke-width="0" c_etype="pad_outer"/><polygon points="4114.882 3694.572 4114.821 3694.562 4114.766 3694.534 4114.723 3694.491 4114.695 3694.436 4114.685 3694.375 4114.685 3689.454 4114.695 3689.393 4114.723 3689.338 4114.766 3689.295 4114.821 3689.267 4114.882 3689.257 4116.063 3689.257 4116.124 3689.267 4116.179 3689.295 4116.222 3689.338 4116.25 3689.393 4116.26 3689.454 4116.26 3694.375 4116.25 3694.436 4116.222 3694.491 4116.179 3694.534 4116.124 3694.562 4116.063 3694.572" stroke-width="0" c_etype="pad_outer"/><polygon points="4112.913 3694.572 4112.852 3694.562 4112.797 3694.534 4112.754 3694.491 4112.726 3694.436 4112.716 3694.375 4112.716 3689.454 4112.726 3689.393 4112.754 3689.338 4112.797 3689.295 4112.852 3689.267 4112.913 3689.257 4114.095 3689.257 4114.156 3689.267 4114.211 3689.295 4114.254 3689.338 4114.282 3689.393 4114.292 3689.454 4114.292 3694.375 4114.282 3694.436 4114.254 3694.491 4114.211 3694.534 4114.156 3694.562 4114.095 3694.572" stroke-width="0" c_etype="pad_outer"/><polygon points="4110.945 3694.572 4110.884 3694.562 4110.829 3694.534 4110.786 3694.491 4110.758 3694.436 4110.748 3694.375 4110.748 3689.454 4110.758 3689.393 4110.786 3689.338 4110.829 3689.295 4110.884 3689.267 4110.945 3689.257 4112.126 3689.257 4112.187 3689.267 4112.242 3689.295 4112.285 3689.338 4112.313 3689.393 4112.323 3689.454 4112.323 3694.375 4112.313 3694.436 4112.285 3694.491 4112.242 3694.534 4112.187 3694.562 4112.126 3694.572" stroke-width="0" c_etype="pad_outer"/><polygon points="4108.976 3694.572 4108.915 3694.562 4108.86 3694.534 4108.817 3694.491 4108.789 3694.436 4108.779 3694.375 4108.779 3689.454 4108.789 3689.393 4108.817 3689.338 4108.86 3689.295 4108.915 3689.267 4108.976 3689.257 4110.158 3689.257 4110.219 3689.267 4110.274 3689.295 4110.317 3689.338 4110.345 3689.393 4110.355 3689.454 4110.355 3694.375 4110.345 3694.436 4110.317 3694.491 4110.274 3694.534 4110.219 3694.562 4110.158 3694.572" stroke-width="0" c_etype="pad_outer"/><polygon points="4107.008 3694.572 4106.947 3694.562 4106.892 3694.534 4106.849 3694.491 4106.821 3694.436 4106.811 3694.375 4106.811 3689.454 4106.821 3689.393 4106.849 3689.338 4106.892 3689.295 4106.947 3689.267 4107.008 3689.257 4108.189 3689.257 4108.25 3689.267 4108.305 3689.295 4108.348 3689.338 4108.376 3689.393 4108.386 3689.454 4108.386 3694.375 4108.376 3694.436 4108.348 3694.491 4108.305 3694.534 4108.25 3694.562 4108.189 3694.572" stroke-width="0" c_etype="pad_outer"/><polygon points="4105.039 3694.572 4104.978 3694.562 4104.923 3694.534 4104.88 3694.491 4104.852 3694.436 4104.842 3694.375 4104.842 3689.454 4104.852 3689.393 4104.88 3689.338 4104.923 3689.295 4104.978 3689.267 4105.039 3689.257 4106.221 3689.257 4106.282 3689.267 4106.337 3689.295 4106.38 3689.338 4106.408 3689.393 4106.418 3689.454 4106.418 3694.375 4106.408 3694.436 4106.38 3694.491 4106.337 3694.534 4106.282 3694.562 4106.221 3694.572" stroke-width="0" c_etype="pad_outer"/><polygon points="4103.071 3694.572 4103.01 3694.562 4102.955 3694.534 4102.912 3694.491 4102.884 3694.436 4102.874 3694.375 4102.874 3689.454 4102.884 3689.393 4102.912 3689.338 4102.955 3689.295 4103.01 3689.267 4103.071 3689.257 4104.252 3689.257 4104.313 3689.267 4104.368 3689.295 4104.411 3689.338 4104.439 3689.393 4104.449 3689.454 4104.449 3694.375 4104.439 3694.436 4104.411 3694.491 4104.368 3694.534 4104.313 3694.562 4104.252 3694.572" stroke-width="0" c_etype="pad_outer"/><polygon points="4101.102 3694.572 4101.041 3694.562 4100.986 3694.534 4100.943 3694.491 4100.915 3694.436 4100.905 3694.375 4100.905 3689.454 4100.915 3689.393 4100.943 3689.338 4100.986 3689.295 4101.041 3689.267 4101.102 3689.257 4102.284 3689.257 4102.345 3689.267 4102.4 3689.295 4102.443 3689.338 4102.471 3689.393 4102.481 3689.454 4102.481 3694.375 4102.471 3694.436 4102.443 3694.491 4102.4 3694.534 4102.345 3694.562 4102.284 3694.572" stroke-width="0" c_etype="pad_outer"/><polygon points="4099.134 3694.572 4099.073 3694.562 4099.018 3694.534 4098.975 3694.491 4098.947 3694.436 4098.937 3694.375 4098.937 3689.454 4098.947 3689.393 4098.975 3689.338 4099.018 3689.295 4099.073 3689.267 4099.134 3689.257 4100.315 3689.257 4100.376 3689.267 4100.431 3689.295 4100.474 3689.338 4100.502 3689.393 4100.512 3689.454 4100.512 3694.375 4100.502 3694.436 4100.474 3694.491 4100.431 3694.534 4100.376 3694.562 4100.315 3694.572" stroke-width="0" c_etype="pad_outer"/><polygon points="4097.165 3694.572 4097.104 3694.562 4097.049 3694.534 4097.006 3694.491 4096.978 3694.436 4096.968 3694.375 4096.968 3689.454 4096.978 3689.393 4097.006 3689.338 4097.049 3689.295 4097.104 3689.267 4097.165 3689.257 4098.347 3689.257 4098.408 3689.267 4098.463 3689.295 4098.506 3689.338 4098.534 3689.393 4098.544 3689.454 4098.544 3694.375 4098.534 3694.436 4098.506 3694.491 4098.463 3694.534 4098.408 3694.562 4098.347 3694.572" stroke-width="0" c_etype="pad_outer"/><ellipse cx="4159.173" cy="3600.724" rx="4.137" ry="4.137" stroke-width="0" c_etype="pad_outer"/><ellipse cx="4109.173" cy="3600.724" rx="4.137" ry="4.137" stroke-width="0" c_etype="pad_outer"/><ellipse cx="4027.48" cy="3797.574" rx="2.9559" ry="2.9559" stroke-width="0" c_etype="pad_outer"/><ellipse cx="4067.638" cy="3797.574" rx="2.9559" ry="2.9559" stroke-width="0" c_etype="pad_outer"/><ellipse cx="4086.535" cy="3797.574" rx="2.9559" ry="2.9559" stroke-width="0" c_etype="pad_outer"/><ellipse cx="4126.693" cy="3797.574" rx="2.9559" ry="2.9559" stroke-width="0" c_etype="pad_outer"/><ellipse cx="4145.59" cy="3797.574" rx="2.9559" ry="2.9559" stroke-width="0" c_etype="pad_outer"/><ellipse cx="4185.748" cy="3797.574" rx="2.9559" ry="2.9559" stroke-width="0" c_etype="pad_outer"/><ellipse cx="4027.48" cy="3858.5975" rx="2.9559" ry="2.9559" stroke-width="0" c_etype="pad_outer"/><ellipse cx="4067.638" cy="3858.5975" rx="2.9559" ry="2.9559" stroke-width="0" c_etype="pad_outer"/><ellipse cx="4086.535" cy="3858.5975" rx="2.9559" ry="2.9559" stroke-width="0" c_etype="pad_outer"/><ellipse cx="4126.693" cy="3858.5975" rx="2.9559" ry="2.9559" stroke-width="0" c_etype="pad_outer"/><ellipse cx="4145.59" cy="3858.5975" rx="2.9559" ry="2.9559" stroke-width="0" c_etype="pad_outer"/><ellipse cx="4185.748" cy="3858.5975" rx="2.9559" ry="2.9559" stroke-width="0" c_etype="pad_outer"/><ellipse cx="4094.409" cy="3773.952" rx="2.9559" ry="2.9559" stroke-width="0" c_etype="pad_outer"/><ellipse cx="4134.567" cy="3773.952" rx="2.9559" ry="2.9559" stroke-width="0" c_etype="pad_outer"/><ellipse cx="4149.527" cy="3773.952" rx="2.9559" ry="2.9559" stroke-width="0" c_etype="pad_outer"/><ellipse cx="4189.685" cy="3773.952" rx="2.9559" ry="2.9559" stroke-width="0" c_etype="pad_outer"/><ellipse cx="4149.527" cy="3750.33" rx="2.9559" ry="2.9559" stroke-width="0" c_etype="pad_outer"/><ellipse cx="4189.685" cy="3750.33" rx="2.9559" ry="2.9559" stroke-width="0" c_etype="pad_outer"/><ellipse cx="4149.527" cy="3691.275" rx="2.9559" ry="2.9559" stroke-width="0" c_etype="pad_outer"/><ellipse cx="4189.685" cy="3691.275" rx="2.9559" ry="2.9559" stroke-width="0" c_etype="pad_outer"/><ellipse cx="4149.527" cy="3671.59" rx="2.9559" ry="2.9559" stroke-width="0" c_etype="pad_outer"/><ellipse cx="4189.685" cy="3671.59" rx="2.9559" ry="2.9559" stroke-width="0" c_etype="pad_outer"/><ellipse cx="4031.417" cy="3691.275" rx="2.9559" ry="2.9559" stroke-width="0" c_etype="pad_outer"/><ellipse cx="4071.575" cy="3691.275" rx="2.9559" ry="2.9559" stroke-width="0" c_etype="pad_outer"/><polygon points="4040.039 3847.813 4039.977 3847.803 4039.921 3847.775 4039.877 3847.731 4039.849 3847.675 4039.839 3847.613 4039.839 3840.527 4039.849 3840.465 4039.877 3840.409 4039.921 3840.365 4039.977 3840.337 4040.039 3840.327 4047.126 3840.327 4047.188 3840.337 4047.244 3840.365 4047.288 3840.409 4047.316 3840.465 4047.326 3840.527 4047.326 3847.613 4047.316 3847.675 4047.288 3847.731 4047.244 3847.775 4047.188 3847.803 4047.126 3847.813" stroke-width="0" c_etype="pad_outer"/><ellipse cx="4053.5825" cy="3844.07" rx="3.7433" ry="3.7433" stroke-width="0" c_etype="pad_outer"/><ellipse cx="4063.5825" cy="3844.07" rx="3.7433" ry="3.7433" stroke-width="0" c_etype="pad_outer"/><ellipse cx="4073.5825" cy="3844.07" rx="3.7433" ry="3.7433" stroke-width="0" c_etype="pad_outer"/><ellipse cx="4083.5825" cy="3844.07" rx="3.7433" ry="3.7433" stroke-width="0" c_etype="pad_outer"/><ellipse cx="4093.5825" cy="3844.07" rx="3.7433" ry="3.7433" stroke-width="0" c_etype="pad_outer"/><ellipse cx="4103.5825" cy="3844.07" rx="3.7433" ry="3.7433" stroke-width="0" c_etype="pad_outer"/><ellipse cx="4113.5825" cy="3844.07" rx="3.7433" ry="3.7433" stroke-width="0" c_etype="pad_outer"/><ellipse cx="4123.5825" cy="3844.07" rx="3.7433" ry="3.7433" stroke-width="0" c_etype="pad_outer"/><ellipse cx="4133.5825" cy="3844.07" rx="3.7433" ry="3.7433" stroke-width="0" c_etype="pad_outer"/><ellipse cx="4143.5825" cy="3844.07" rx="3.7433" ry="3.7433" stroke-width="0" c_etype="pad_outer"/><ellipse cx="4153.5825" cy="3844.07" rx="3.7433" ry="3.7433" stroke-width="0" c_etype="pad_outer"/><ellipse cx="4163.5825" cy="3844.07" rx="3.7433" ry="3.7433" stroke-width="0" c_etype="pad_outer"/><ellipse cx="4173.5825" cy="3844.07" rx="3.7433" ry="3.7433" stroke-width="0" c_etype="pad_outer"/><ellipse cx="4173.5825" cy="3814.07" rx="3.7433" ry="3.7433" stroke-width="0" c_etype="pad_outer"/><ellipse cx="4163.5825" cy="3814.07" rx="3.7433" ry="3.7433" stroke-width="0" c_etype="pad_outer"/><ellipse cx="4153.5825" cy="3814.07" rx="3.7433" ry="3.7433" stroke-width="0" c_etype="pad_outer"/><ellipse cx="4143.5825" cy="3814.07" rx="3.7433" ry="3.7433" stroke-width="0" c_etype="pad_outer"/><ellipse cx="4133.5825" cy="3814.07" rx="3.7433" ry="3.7433" stroke-width="0" c_etype="pad_outer"/><ellipse cx="4123.5825" cy="3814.07" rx="3.7433" ry="3.7433" stroke-width="0" c_etype="pad_outer"/><ellipse cx="4113.5825" cy="3814.07" rx="3.7433" ry="3.7433" stroke-width="0" c_etype="pad_outer"/><ellipse cx="4103.5825" cy="3814.07" rx="3.7433" ry="3.7433" stroke-width="0" c_etype="pad_outer"/><ellipse cx="4093.5825" cy="3814.07" rx="3.7433" ry="3.7433" stroke-width="0" c_etype="pad_outer"/><ellipse cx="4083.5825" cy="3814.07" rx="3.7433" ry="3.7433" stroke-width="0" c_etype="pad_outer"/><ellipse cx="4073.5825" cy="3814.07" rx="3.7433" ry="3.7433" stroke-width="0" c_etype="pad_outer"/><ellipse cx="4063.5825" cy="3814.07" rx="3.7433" ry="3.7433" stroke-width="0" c_etype="pad_outer"/><ellipse cx="4053.5825" cy="3814.07" rx="3.7433" ry="3.7433" stroke-width="0" c_etype="pad_outer"/><ellipse cx="4043.5825" cy="3814.07" rx="3.7433" ry="3.7433" stroke-width="0" c_etype="pad_outer"/></g></mask><mask id="bottomBoardSolderMask" maskUnits="userSpaceOnUse" x="4020" y="3396" width="177.2" height="472.4"><path d="M4035.7493 3868.44,4035.3938 3868.4359,4035.3881 3868.4357,4035.0416 3868.4241,4035.036 3868.4238,4034.6849 3868.404,4034.6794 3868.4036,4034.3336 3868.3762,4034.328 3868.3757,4033.9828 3868.3407,4033.9771 3868.3401,4033.6243 3868.2961,4033.6186 3868.2953,4033.2793 3868.2451,4033.2739 3868.2443,4032.9234 3868.1846,4032.9178 3868.1835,4032.5809 3868.1181,4032.5754 3868.117,4032.2322 3868.0425,4032.2267 3868.0412,4031.8857 3867.959,4031.8801 3867.9576,4031.5416 3867.8677,4031.5363 3867.8662,4031.2031 3867.7699,4031.1976 3867.7682,4030.8647 3867.6636,4030.8595 3867.6619,4030.5274 3867.5494,4030.522 3867.5475,4030.1925 3867.4275,4030.1871 3867.4255,4029.8629 3867.2989,4029.8577 3867.2968,4029.538 3867.1638,4029.5328 3867.1616,4029.2094 3867.0183,4029.2043 3867.0159,4028.8911 3866.8688,4028.8861 3866.8663,4028.5712 3866.7096,4028.566 3866.707,4028.2579 3866.5447,4028.2531 3866.542,4027.9474 3866.3722,4027.9425 3866.3695,4027.6422 3866.1938,4027.6373 3866.1908,4027.3381 3866.0063,4027.3333 3866.0033,4027.0435 3865.8155,4027.039 3865.8125,4026.745 3865.6127,4026.7403 3865.6094,4026.4594 3865.409,4026.4549 3865.4057,4026.1728 3865.1946,4026.1683 3865.1912,4025.8984 3864.9796,4025.894 3864.976,4025.6166 3864.7482,4025.6123 3864.7446,4025.3533 3864.522,4025.3491 3864.5183,4025.0882 3864.2837,4025.084 3864.2799,4024.8293 3864.0401,4024.8253 3864.0363,4024.5751 3863.79,4024.571 3863.7859,4024.3292 3863.5367,4024.3253 3863.5327,4024.0889 3863.278,4024.0852 3863.2739,4023.8503 3863.009,4023.8466 3863.0048,4023.6243 3862.7426,4023.6206 3862.7383,4023.3976 3862.4627,4023.3942 3862.4582,4023.1824 3862.1844,4023.179 3862.1799,4022.9715 3861.8984,4022.9683 3861.8939,4022.7651 3861.605,4022.7619 3861.6004,4022.569 3861.3125,4022.5659 3861.3078,4022.3796 3861.0159,4022.3765 3861.011,4022.195 3860.7116,4022.1922 3860.7068,4022.0156 3860.4005,4022.0128 3860.3955,4021.8473 3860.0927,4021.8447 3860.0877,4021.6827 3859.7749,4021.6802 3859.7699,4021.5282 3859.4593,4021.5258 3859.4542,4021.3762 3859.1301,4021.3739 3859.125,4021.2371 3858.8105,4021.2348 3858.8052,4021.1025 3858.4807,4021.1005 3858.4755,4020.9772 3858.153,4020.9752 3858.1477,4020.8556 3857.8123,4020.8537 3857.8069,4020.7462 3857.4821,4020.7446 3857.4768,4020.6401 3857.1361,4020.6385 3857.1307,4020.5453 3856.8,4020.5438 3856.7945,4020.4554 3856.4514,4020.4541 3856.446,4020.3751 3856.1089,4020.3738 3856.1033,4020.3021 3855.7617,4020.301 3855.7562,4020.2363 3855.4102,4020.2354 3855.4046,4020.1794 3855.0624,4020.1785 3855.0568,4020.1302 3854.7123,4020.1294 3854.7067,4020.0885 3854.3589,4020.0879 3854.3533,4020.0547 3854.0033,4020.0543 3853.9977,4020.0291 3853.6509,4020.0288 3853.6451,4020.0115 3853.2947,4020.0113 3853.2891,4020.002 3852.9426,4020.0019 3852.9377,4019.9999 3852.691,4020 3852.689,4020 3411.7504,4019.9999 3411.7476,4020.004 3411.3938,4020.0042 3411.3881,4020.0158 3411.0416,4020.0161 3411.036,4020.0359 3410.6849,4020.0363 3410.6794,4020.0637 3410.3336,4020.0642 3410.328,4020.0992 3409.9828,4020.0998 3409.9771,4020.1438 3409.6243,4020.1446 3409.6186,4020.1948 3409.2793,4020.1956 3409.2739,4020.2553 3408.9234,4020.2564 3408.9178,4020.3218 3408.5809,4020.3229 3408.5754,4020.3974 3408.2322,4020.3987 3408.2267,4020.4809 3407.8857,4020.4823 3407.8801,4020.5722 3407.5416,4020.5737 3407.5363,4020.67 3407.2031,4020.6717 3407.1976,4020.7763 3406.8647,4020.778 3406.8595,4020.8905 3406.5274,4020.8924 3406.522,4021.0124 3406.1925,4021.0144 3406.1871,4021.141 3405.8629,4021.1431 3405.8577,4021.2761 3405.538,4021.2783 3405.5328,4021.4216 3405.2094,4021.424 3405.2043,4021.5711 3404.8911,4021.5736 3404.8861,4021.7303 3404.5712,4021.7329 3404.566,4021.8952 3404.2579,4021.8979 3404.2531,4022.0677 3403.9474,4022.0704 3403.9425,4022.2461 3403.6422,4022.2491 3403.6373,4022.4336 3403.3381,4022.4366 3403.3333,4022.6244 3403.0435,4022.6274 3403.039,4022.8272 3402.745,4022.8305 3402.7403,4023.0309 3402.4594,4023.0342 3402.4549,4023.2453 3402.1728,4023.2487 3402.1683,4023.4593 3401.8996,4023.4628 3401.8952,4023.6917 3401.6165,4023.6953 3401.6123,4023.9179 3401.3533,4023.9216 3401.3491,4024.1562 3401.0882,4024.16 3401.084,4024.3998 3400.8293,4024.4036 3400.8253,4024.6499 3400.5751,4024.654 3400.571,4024.9032 3400.3292,4024.9072 3400.3253,4025.1619 3400.0889,4025.166 3400.0852,4025.4309 3399.8503,4025.4351 3399.8466,4025.6973 3399.6243,4025.7016 3399.6206,4025.9772 3399.3976,4025.9817 3399.3942,4026.2555 3399.1824,4026.26 3399.179,4026.5415 3398.9715,4026.546 3398.9683,4026.8349 3398.7651,4026.8395 3398.7619,4027.1274 3398.569,4027.1321 3398.5659,4027.424 3398.3796,4027.4289 3398.3765,4027.7283 3398.195,4027.7331 3398.1922,4028.0394 3398.0156,4028.0444 3398.0128,4028.3472 3397.8473,4028.3522 3397.8447,4028.665 3397.6827,4028.67 3397.6802,4028.9806 3397.5282,4028.9857 3397.5257,4029.309 3397.3765,4029.314 3397.3743,4029.6293 3397.2371,4029.6347 3397.2348,4029.9592 3397.1025,4029.9644 3397.1005,4030.2869 3396.9772,4030.2922 3396.9752,4030.6276 3396.8556,4030.633 3396.8537,4030.9578 3396.7462,4030.9631 3396.7446,4031.3038 3396.6401,4031.3092 3396.6385,4031.6399 3396.5453,4031.6454 3396.5438,4031.9885 3396.4554,4031.9939 3396.4541,4032.331 3396.3751,4032.3366 3396.3738,4032.6782 3396.3021,4032.6837 3396.301,4033.0297 3396.2363,4033.0353 3396.2354,4033.3775 3396.1794,4033.3831 3396.1785,4033.7276 3396.1302,4033.7332 3396.1294,4034.081 3396.0885,4034.0866 3396.0879,4034.4366 3396.0547,4034.4422 3396.0543,4034.789 3396.0291,4034.7948 3396.0288,4035.1452 3396.0115,4035.1508 3396.0113,4035.4973 3396.002,4035.5022 3396.0019,4035.7489 3395.9999,4035.7509 3396,4181.4128 3396,4181.4156 3395.9999,4181.7711 3396.004,4181.7768 3396.0042,4182.1233 3396.0158,4182.1289 3396.0161,4182.48 3396.0359,4182.4855 3396.0363,4182.8313 3396.0637,4182.8369 3396.0642,4183.1821 3396.0992,4183.1878 3396.0998,4183.5406 3396.1438,4183.5463 3396.1446,4183.8856 3396.1948,4183.891 3396.1956,4184.2415 3396.2553,4184.2471 3396.2564,4184.584 3396.3218,4184.5895 3396.3229,4184.9327 3396.3974,4184.9382 3396.3987,4185.2792 3396.4809,4185.2848 3396.4823,4185.6233 3396.5722,4185.6286 3396.5737,4185.9618 3396.67,4185.9673 3396.6717,4186.3002 3396.7763,4186.3054 3396.778,4186.6375 3396.8905,4186.6429 3396.8924,4186.9724 3397.0124,4186.9778 3397.0144,4187.302 3397.141,4187.3072 3397.1431,4187.6269 3397.2761,4187.6321 3397.2783,4187.9555 3397.4216,4187.9606 3397.424,4188.2738 3397.5711,4188.2788 3397.5736,4188.5937 3397.7303,4188.5989 3397.7329,4188.907 3397.8952,4188.9118 3397.8979,4189.2175 3398.0677,4189.2224 3398.0704,4189.5227 3398.2461,4189.5276 3398.2491,4189.8268 3398.4336,4189.8316 3398.4366,4190.1214 3398.6244,4190.1259 3398.6274,4190.4199 3398.8272,4190.4246 3398.8305,4190.7055 3399.0309,4190.71 3399.0342,4190.9921 3399.2453,4190.9966 3399.2487,4191.2665 3399.4603,4191.2709 3399.4639,4191.5483 3399.6917,4191.5526 3399.6953,4191.8116 3399.9179,4191.8158 3399.9216,4192.0767 3400.1562,4192.0809 3400.16,4192.3356 3400.3998,4192.3396 3400.4036,4192.5898 3400.6499,4192.5939 3400.654,4192.8357 3400.9032,4192.8396 3400.9072,4193.076 3401.1619,4193.0797 3401.166,4193.3146 3401.4309,4193.3183 3401.4351,4193.5406 3401.6973,4193.5443 3401.7016,4193.7673 3401.9772,4193.7707 3401.9817,4193.9825 3402.2555,4193.9859 3402.26,4194.1924 3402.5401,4194.1956 3402.5446,4194.3998 3402.8349,4194.403 3402.8395,4194.5959 3403.1274,4194.599 3403.1321,4194.7853 3403.424,4194.7884 3403.4289,4194.9699 3403.7283,4194.9727 3403.7331,4195.1493 3404.0394,4195.1521 3404.0444,4195.3176 3404.3472,4195.3202 3404.3522,4195.4822 3404.665,4195.4847 3404.67,4195.6367 3404.9806,4195.6391 3404.9857,4195.7887 3405.3098,4195.791 3405.3149,4195.9278 3405.6294,4195.9301 3405.6347,4196.0624 3405.9592,4196.0644 3405.9644,4196.1877 3406.2869,4196.1897 3406.2922,4196.3093 3406.6276,4196.3111 3406.6329,4196.4181 3406.9559,4196.4199 3406.9613,4196.5249 3407.3038,4196.5264 3407.3092,4196.6196 3407.6399,4196.6211 3407.6454,4196.7095 3407.9885,4196.7108 3407.9939,4196.7898 3408.331,4196.7911 3408.3366,4196.8628 3408.6782,4196.8639 3408.6837,4196.9286 3409.0297,4196.9295 3409.0353,4196.9855 3409.3775,4196.9864 3409.3831,4197.0347 3409.7276,4197.0355 3409.7332,4197.0764 3410.081,4197.077 3410.0866,4197.1102 3410.4366,4197.1106 3410.4422,4197.1358 3410.789,4197.1361 3410.7948,4197.1534 3411.1452,4197.1536 3411.1508,4197.1629 3411.4973,4197.163 3411.5021,4197.165 3411.7449,4197.165 3852.6906,4197.1609 3853.0461,4197.1607 3853.0518,4197.1491 3853.3983,4197.1488 3853.4039,4197.129 3853.755,4197.1286 3853.7605,4197.1012 3854.1063,4197.1007 3854.1119,4197.0657 3854.4571,4197.0651 3854.4628,4197.0211 3854.8156,4197.0203 3854.8213,4196.9701 3855.1606,4196.9693 3855.166,4196.9096 3855.5165,4196.9085 3855.5221,4196.8431 3855.859,4196.842 3855.8645,4196.7675 3856.2077,4196.7662 3856.2132,4196.684 3856.5542,4196.6826 3856.5598,4196.5927 3856.8983,4196.5912 3856.9036,4196.4949 3857.2368,4196.4932 3857.2423,4196.3886 3857.5752,4196.3869 3857.5804,4196.2744 3857.9125,4196.2725 3857.9179,4196.1525 3858.2474,4196.1505 3858.2528,4196.0239 3858.577,4196.0218 3858.5822,4195.8888 3858.9019,4195.8866 3858.9071,4195.7433 3859.2305,4195.7409 3859.2356,4195.5938 3859.5488,4195.5913 3859.5538,4195.4346 3859.8687,4195.432 3859.8739,4195.2697 3860.182,4195.267 3860.1868,4195.0972 3860.4925,4195.0945 3860.4974,4194.9188 3860.7977,4194.9158 3860.8026,4194.7313 3861.1018,4194.7283 3861.1066,4194.5405 3861.3964,4194.5375 3861.4009,4194.3377 3861.6949,4194.3344 3861.6996,4194.134 3861.9805,4194.1307 3861.985,4193.9196 3862.2671,4193.9162 3862.2716,4193.7056 3862.5403,4193.7021 3862.5447,4193.4736 3862.8229,4193.47 3862.8271,4193.247 3863.0866,4193.2433 3863.0908,4193.0087 3863.3517,4193.0049 3863.3559,4192.7651 3863.6106,4192.7613 3863.6146,4192.515 3863.8648,4192.5109 3863.8689,4192.2617 3864.1107,4192.2577 3864.1146,4192.003 3864.351,4191.9989 3864.3547,4191.734 3864.5896,4191.7298 3864.5933,4191.4676 3864.8156,4191.4633 3864.8193,4191.1877 3865.0423,4191.1832 3865.0457,4190.9094 3865.2575,4190.9049 3865.2609,4190.6234 3865.4684,4190.6189 3865.4716,4190.33 3865.6748,4190.3254 3865.678,4190.0375 3865.8709,4190.0328 3865.874,4189.7409 3866.0603,4189.736 3866.0634,4189.4366 3866.2449,4189.4318 3866.2477,4189.1255 3866.4243,4189.1205 3866.4271,4188.8177 3866.5926,4188.8127 3866.5952,4188.4999 3866.7572,4188.4949 3866.7597,4188.1843 3866.9117,4188.1792 3866.9142,4187.8559 3867.0634,4187.8509 3867.0656,4187.5356 3867.2028,4187.5302 3867.2051,4187.2057 3867.3374,4187.2005 3867.3394,4186.878 3867.4627,4186.8727 3867.4647,4186.5373 3867.5843,4186.5319 3867.5862,4186.2071 3867.6937,4186.2018 3867.6953,4185.8611 3867.7998,4185.8557 3867.8014,4185.525 3867.8946,4185.5195 3867.8961,4185.1764 3867.9845,4185.171 3867.9858,4184.8339 3868.0648,4184.8283 3868.0661,4184.4867 3868.1378,4184.4812 3868.1389,4184.1352 3868.2036,4184.1296 3868.2045,4183.7874 3868.2605,4183.7818 3868.2614,4183.4373 3868.3097,4183.4317 3868.3105,4183.0839 3868.3514,4183.0783 3868.352,4182.7283 3868.3852,4182.7227 3868.3856,4182.3759 3868.4108,4182.3701 3868.4111,4182.0197 3868.4284,4182.0141 3868.4286,4181.6676 3868.4379,4181.6627 3868.438,4181.416 3868.44z" stroke="none" fill="white"/><g fill="black"><ellipse cx="4159.173" cy="3600.724" rx="4.137" ry="4.137" stroke-width="0" c_etype="pad_outer"/><ellipse cx="4109.173" cy="3600.724" rx="4.137" ry="4.137" stroke-width="0" c_etype="pad_outer"/><ellipse cx="4027.48" cy="3797.574" rx="2.9559" ry="2.9559" stroke-width="0" c_etype="pad_outer"/><ellipse cx="4067.638" cy="3797.574" rx="2.9559" ry="2.9559" stroke-width="0" c_etype="pad_outer"/><ellipse cx="4086.535" cy="3797.574" rx="2.9559" ry="2.9559" stroke-width="0" c_etype="pad_outer"/><ellipse cx="4126.693" cy="3797.574" rx="2.9559" ry="2.9559" stroke-width="0" c_etype="pad_outer"/><ellipse cx="4145.59" cy="3797.574" rx="2.9559" ry="2.9559" stroke-width="0" c_etype="pad_outer"/><ellipse cx="4185.748" cy="3797.574" rx="2.9559" ry="2.9559" stroke-width="0" c_etype="pad_outer"/><ellipse cx="4027.48" cy="3858.5975" rx="2.9559" ry="2.9559" stroke-width="0" c_etype="pad_outer"/><ellipse cx="4067.638" cy="3858.5975" rx="2.9559" ry="2.9559" stroke-width="0" c_etype="pad_outer"/><ellipse cx="4086.535" cy="3858.5975" rx="2.9559" ry="2.9559" stroke-width="0" c_etype="pad_outer"/><ellipse cx="4126.693" cy="3858.5975" rx="2.9559" ry="2.9559" stroke-width="0" c_etype="pad_outer"/><ellipse cx="4145.59" cy="3858.5975" rx="2.9559" ry="2.9559" stroke-width="0" c_etype="pad_outer"/><ellipse cx="4185.748" cy="3858.5975" rx="2.9559" ry="2.9559" stroke-width="0" c_etype="pad_outer"/><ellipse cx="4094.409" cy="3773.952" rx="2.9559" ry="2.9559" stroke-width="0" c_etype="pad_outer"/><ellipse cx="4134.567" cy="3773.952" rx="2.9559" ry="2.9559" stroke-width="0" c_etype="pad_outer"/><ellipse cx="4149.527" cy="3773.952" rx="2.9559" ry="2.9559" stroke-width="0" c_etype="pad_outer"/><ellipse cx="4189.685" cy="3773.952" rx="2.9559" ry="2.9559" stroke-width="0" c_etype="pad_outer"/><ellipse cx="4149.527" cy="3750.33" rx="2.9559" ry="2.9559" stroke-width="0" c_etype="pad_outer"/><ellipse cx="4189.685" cy="3750.33" rx="2.9559" ry="2.9559" stroke-width="0" c_etype="pad_outer"/><ellipse cx="4149.527" cy="3691.275" rx="2.9559" ry="2.9559" stroke-width="0" c_etype="pad_outer"/><ellipse cx="4189.685" cy="3691.275" rx="2.9559" ry="2.9559" stroke-width="0" c_etype="pad_outer"/><ellipse cx="4149.527" cy="3671.59" rx="2.9559" ry="2.9559" stroke-width="0" c_etype="pad_outer"/><ellipse cx="4189.685" cy="3671.59" rx="2.9559" ry="2.9559" stroke-width="0" c_etype="pad_outer"/><ellipse cx="4031.417" cy="3691.275" rx="2.9559" ry="2.9559" stroke-width="0" c_etype="pad_outer"/><ellipse cx="4071.575" cy="3691.275" rx="2.9559" ry="2.9559" stroke-width="0" c_etype="pad_outer"/><polygon points="4040.039 3847.813 4039.977 3847.803 4039.921 3847.775 4039.877 3847.731 4039.849 3847.675 4039.839 3847.613 4039.839 3840.527 4039.849 3840.465 4039.877 3840.409 4039.921 3840.365 4039.977 3840.337 4040.039 3840.327 4047.126 3840.327 4047.188 3840.337 4047.244 3840.365 4047.288 3840.409 4047.316 3840.465 4047.326 3840.527 4047.326 3847.613 4047.316 3847.675 4047.288 3847.731 4047.244 3847.775 4047.188 3847.803 4047.126 3847.813" stroke-width="0" c_etype="pad_outer"/><ellipse cx="4053.5825" cy="3844.07" rx="3.7433" ry="3.7433" stroke-width="0" c_etype="pad_outer"/><ellipse cx="4063.5825" cy="3844.07" rx="3.7433" ry="3.7433" stroke-width="0" c_etype="pad_outer"/><ellipse cx="4073.5825" cy="3844.07" rx="3.7433" ry="3.7433" stroke-width="0" c_etype="pad_outer"/><ellipse cx="4083.5825" cy="3844.07" rx="3.7433" ry="3.7433" stroke-width="0" c_etype="pad_outer"/><ellipse cx="4093.5825" cy="3844.07" rx="3.7433" ry="3.7433" stroke-width="0" c_etype="pad_outer"/><ellipse cx="4103.5825" cy="3844.07" rx="3.7433" ry="3.7433" stroke-width="0" c_etype="pad_outer"/><ellipse cx="4113.5825" cy="3844.07" rx="3.7433" ry="3.7433" stroke-width="0" c_etype="pad_outer"/><ellipse cx="4123.5825" cy="3844.07" rx="3.7433" ry="3.7433" stroke-width="0" c_etype="pad_outer"/><ellipse cx="4133.5825" cy="3844.07" rx="3.7433" ry="3.7433" stroke-width="0" c_etype="pad_outer"/><ellipse cx="4143.5825" cy="3844.07" rx="3.7433" ry="3.7433" stroke-width="0" c_etype="pad_outer"/><ellipse cx="4153.5825" cy="3844.07" rx="3.7433" ry="3.7433" stroke-width="0" c_etype="pad_outer"/><ellipse cx="4163.5825" cy="3844.07" rx="3.7433" ry="3.7433" stroke-width="0" c_etype="pad_outer"/><ellipse cx="4173.5825" cy="3844.07" rx="3.7433" ry="3.7433" stroke-width="0" c_etype="pad_outer"/><ellipse cx="4173.5825" cy="3814.07" rx="3.7433" ry="3.7433" stroke-width="0" c_etype="pad_outer"/><ellipse cx="4163.5825" cy="3814.07" rx="3.7433" ry="3.7433" stroke-width="0" c_etype="pad_outer"/><ellipse cx="4153.5825" cy="3814.07" rx="3.7433" ry="3.7433" stroke-width="0" c_etype="pad_outer"/><ellipse cx="4143.5825" cy="3814.07" rx="3.7433" ry="3.7433" stroke-width="0" c_etype="pad_outer"/><ellipse cx="4133.5825" cy="3814.07" rx="3.7433" ry="3.7433" stroke-width="0" c_etype="pad_outer"/><ellipse cx="4123.5825" cy="3814.07" rx="3.7433" ry="3.7433" stroke-width="0" c_etype="pad_outer"/><ellipse cx="4113.5825" cy="3814.07" rx="3.7433" ry="3.7433" stroke-width="0" c_etype="pad_outer"/><ellipse cx="4103.5825" cy="3814.07" rx="3.7433" ry="3.7433" stroke-width="0" c_etype="pad_outer"/><ellipse cx="4093.5825" cy="3814.07" rx="3.7433" ry="3.7433" stroke-width="0" c_etype="pad_outer"/><ellipse cx="4083.5825" cy="3814.07" rx="3.7433" ry="3.7433" stroke-width="0" c_etype="pad_outer"/><ellipse cx="4073.5825" cy="3814.07" rx="3.7433" ry="3.7433" stroke-width="0" c_etype="pad_outer"/><ellipse cx="4063.5825" cy="3814.07" rx="3.7433" ry="3.7433" stroke-width="0" c_etype="pad_outer"/><ellipse cx="4053.5825" cy="3814.07" rx="3.7433" ry="3.7433" stroke-width="0" c_etype="pad_outer"/><ellipse cx="4043.5825" cy="3814.07" rx="3.7433" ry="3.7433" stroke-width="0" c_etype="pad_outer"/></g></mask><mask id="bottomSignalSolderMask" maskUnits="userSpaceOnUse" x="4020" y="3396" width="177.2" height="472.4"><path d="M4035.7493 3868.44,4035.3938 3868.4359,4035.3881 3868.4357,4035.0416 3868.4241,4035.036 3868.4238,4034.6849 3868.404,4034.6794 3868.4036,4034.3336 3868.3762,4034.328 3868.3757,4033.9828 3868.3407,4033.9771 3868.3401,4033.6243 3868.2961,4033.6186 3868.2953,4033.2793 3868.2451,4033.2739 3868.2443,4032.9234 3868.1846,4032.9178 3868.1835,4032.5809 3868.1181,4032.5754 3868.117,4032.2322 3868.0425,4032.2267 3868.0412,4031.8857 3867.959,4031.8801 3867.9576,4031.5416 3867.8677,4031.5363 3867.8662,4031.2031 3867.7699,4031.1976 3867.7682,4030.8647 3867.6636,4030.8595 3867.6619,4030.5274 3867.5494,4030.522 3867.5475,4030.1925 3867.4275,4030.1871 3867.4255,4029.8629 3867.2989,4029.8577 3867.2968,4029.538 3867.1638,4029.5328 3867.1616,4029.2094 3867.0183,4029.2043 3867.0159,4028.8911 3866.8688,4028.8861 3866.8663,4028.5712 3866.7096,4028.566 3866.707,4028.2579 3866.5447,4028.2531 3866.542,4027.9474 3866.3722,4027.9425 3866.3695,4027.6422 3866.1938,4027.6373 3866.1908,4027.3381 3866.0063,4027.3333 3866.0033,4027.0435 3865.8155,4027.039 3865.8125,4026.745 3865.6127,4026.7403 3865.6094,4026.4594 3865.409,4026.4549 3865.4057,4026.1728 3865.1946,4026.1683 3865.1912,4025.8984 3864.9796,4025.894 3864.976,4025.6166 3864.7482,4025.6123 3864.7446,4025.3533 3864.522,4025.3491 3864.5183,4025.0882 3864.2837,4025.084 3864.2799,4024.8293 3864.0401,4024.8253 3864.0363,4024.5751 3863.79,4024.571 3863.7859,4024.3292 3863.5367,4024.3253 3863.5327,4024.0889 3863.278,4024.0852 3863.2739,4023.8503 3863.009,4023.8466 3863.0048,4023.6243 3862.7426,4023.6206 3862.7383,4023.3976 3862.4627,4023.3942 3862.4582,4023.1824 3862.1844,4023.179 3862.1799,4022.9715 3861.8984,4022.9683 3861.8939,4022.7651 3861.605,4022.7619 3861.6004,4022.569 3861.3125,4022.5659 3861.3078,4022.3796 3861.0159,4022.3765 3861.011,4022.195 3860.7116,4022.1922 3860.7068,4022.0156 3860.4005,4022.0128 3860.3955,4021.8473 3860.0927,4021.8447 3860.0877,4021.6827 3859.7749,4021.6802 3859.7699,4021.5282 3859.4593,4021.5258 3859.4542,4021.3762 3859.1301,4021.3739 3859.125,4021.2371 3858.8105,4021.2348 3858.8052,4021.1025 3858.4807,4021.1005 3858.4755,4020.9772 3858.153,4020.9752 3858.1477,4020.8556 3857.8123,4020.8537 3857.8069,4020.7462 3857.4821,4020.7446 3857.4768,4020.6401 3857.1361,4020.6385 3857.1307,4020.5453 3856.8,4020.5438 3856.7945,4020.4554 3856.4514,4020.4541 3856.446,4020.3751 3856.1089,4020.3738 3856.1033,4020.3021 3855.7617,4020.301 3855.7562,4020.2363 3855.4102,4020.2354 3855.4046,4020.1794 3855.0624,4020.1785 3855.0568,4020.1302 3854.7123,4020.1294 3854.7067,4020.0885 3854.3589,4020.0879 3854.3533,4020.0547 3854.0033,4020.0543 3853.9977,4020.0291 3853.6509,4020.0288 3853.6451,4020.0115 3853.2947,4020.0113 3853.2891,4020.002 3852.9426,4020.0019 3852.9377,4019.9999 3852.691,4020 3852.689,4020 3411.7504,4019.9999 3411.7476,4020.004 3411.3938,4020.0042 3411.3881,4020.0158 3411.0416,4020.0161 3411.036,4020.0359 3410.6849,4020.0363 3410.6794,4020.0637 3410.3336,4020.0642 3410.328,4020.0992 3409.9828,4020.0998 3409.9771,4020.1438 3409.6243,4020.1446 3409.6186,4020.1948 3409.2793,4020.1956 3409.2739,4020.2553 3408.9234,4020.2564 3408.9178,4020.3218 3408.5809,4020.3229 3408.5754,4020.3974 3408.2322,4020.3987 3408.2267,4020.4809 3407.8857,4020.4823 3407.8801,4020.5722 3407.5416,4020.5737 3407.5363,4020.67 3407.2031,4020.6717 3407.1976,4020.7763 3406.8647,4020.778 3406.8595,4020.8905 3406.5274,4020.8924 3406.522,4021.0124 3406.1925,4021.0144 3406.1871,4021.141 3405.8629,4021.1431 3405.8577,4021.2761 3405.538,4021.2783 3405.5328,4021.4216 3405.2094,4021.424 3405.2043,4021.5711 3404.8911,4021.5736 3404.8861,4021.7303 3404.5712,4021.7329 3404.566,4021.8952 3404.2579,4021.8979 3404.2531,4022.0677 3403.9474,4022.0704 3403.9425,4022.2461 3403.6422,4022.2491 3403.6373,4022.4336 3403.3381,4022.4366 3403.3333,4022.6244 3403.0435,4022.6274 3403.039,4022.8272 3402.745,4022.8305 3402.7403,4023.0309 3402.4594,4023.0342 3402.4549,4023.2453 3402.1728,4023.2487 3402.1683,4023.4593 3401.8996,4023.4628 3401.8952,4023.6917 3401.6165,4023.6953 3401.6123,4023.9179 3401.3533,4023.9216 3401.3491,4024.1562 3401.0882,4024.16 3401.084,4024.3998 3400.8293,4024.4036 3400.8253,4024.6499 3400.5751,4024.654 3400.571,4024.9032 3400.3292,4024.9072 3400.3253,4025.1619 3400.0889,4025.166 3400.0852,4025.4309 3399.8503,4025.4351 3399.8466,4025.6973 3399.6243,4025.7016 3399.6206,4025.9772 3399.3976,4025.9817 3399.3942,4026.2555 3399.1824,4026.26 3399.179,4026.5415 3398.9715,4026.546 3398.9683,4026.8349 3398.7651,4026.8395 3398.7619,4027.1274 3398.569,4027.1321 3398.5659,4027.424 3398.3796,4027.4289 3398.3765,4027.7283 3398.195,4027.7331 3398.1922,4028.0394 3398.0156,4028.0444 3398.0128,4028.3472 3397.8473,4028.3522 3397.8447,4028.665 3397.6827,4028.67 3397.6802,4028.9806 3397.5282,4028.9857 3397.5257,4029.309 3397.3765,4029.314 3397.3743,4029.6293 3397.2371,4029.6347 3397.2348,4029.9592 3397.1025,4029.9644 3397.1005,4030.2869 3396.9772,4030.2922 3396.9752,4030.6276 3396.8556,4030.633 3396.8537,4030.9578 3396.7462,4030.9631 3396.7446,4031.3038 3396.6401,4031.3092 3396.6385,4031.6399 3396.5453,4031.6454 3396.5438,4031.9885 3396.4554,4031.9939 3396.4541,4032.331 3396.3751,4032.3366 3396.3738,4032.6782 3396.3021,4032.6837 3396.301,4033.0297 3396.2363,4033.0353 3396.2354,4033.3775 3396.1794,4033.3831 3396.1785,4033.7276 3396.1302,4033.7332 3396.1294,4034.081 3396.0885,4034.0866 3396.0879,4034.4366 3396.0547,4034.4422 3396.0543,4034.789 3396.0291,4034.7948 3396.0288,4035.1452 3396.0115,4035.1508 3396.0113,4035.4973 3396.002,4035.5022 3396.0019,4035.7489 3395.9999,4035.7509 3396,4181.4128 3396,4181.4156 3395.9999,4181.7711 3396.004,4181.7768 3396.0042,4182.1233 3396.0158,4182.1289 3396.0161,4182.48 3396.0359,4182.4855 3396.0363,4182.8313 3396.0637,4182.8369 3396.0642,4183.1821 3396.0992,4183.1878 3396.0998,4183.5406 3396.1438,4183.5463 3396.1446,4183.8856 3396.1948,4183.891 3396.1956,4184.2415 3396.2553,4184.2471 3396.2564,4184.584 3396.3218,4184.5895 3396.3229,4184.9327 3396.3974,4184.9382 3396.3987,4185.2792 3396.4809,4185.2848 3396.4823,4185.6233 3396.5722,4185.6286 3396.5737,4185.9618 3396.67,4185.9673 3396.6717,4186.3002 3396.7763,4186.3054 3396.778,4186.6375 3396.8905,4186.6429 3396.8924,4186.9724 3397.0124,4186.9778 3397.0144,4187.302 3397.141,4187.3072 3397.1431,4187.6269 3397.2761,4187.6321 3397.2783,4187.9555 3397.4216,4187.9606 3397.424,4188.2738 3397.5711,4188.2788 3397.5736,4188.5937 3397.7303,4188.5989 3397.7329,4188.907 3397.8952,4188.9118 3397.8979,4189.2175 3398.0677,4189.2224 3398.0704,4189.5227 3398.2461,4189.5276 3398.2491,4189.8268 3398.4336,4189.8316 3398.4366,4190.1214 3398.6244,4190.1259 3398.6274,4190.4199 3398.8272,4190.4246 3398.8305,4190.7055 3399.0309,4190.71 3399.0342,4190.9921 3399.2453,4190.9966 3399.2487,4191.2665 3399.4603,4191.2709 3399.4639,4191.5483 3399.6917,4191.5526 3399.6953,4191.8116 3399.9179,4191.8158 3399.9216,4192.0767 3400.1562,4192.0809 3400.16,4192.3356 3400.3998,4192.3396 3400.4036,4192.5898 3400.6499,4192.5939 3400.654,4192.8357 3400.9032,4192.8396 3400.9072,4193.076 3401.1619,4193.0797 3401.166,4193.3146 3401.4309,4193.3183 3401.4351,4193.5406 3401.6973,4193.5443 3401.7016,4193.7673 3401.9772,4193.7707 3401.9817,4193.9825 3402.2555,4193.9859 3402.26,4194.1924 3402.5401,4194.1956 3402.5446,4194.3998 3402.8349,4194.403 3402.8395,4194.5959 3403.1274,4194.599 3403.1321,4194.7853 3403.424,4194.7884 3403.4289,4194.9699 3403.7283,4194.9727 3403.7331,4195.1493 3404.0394,4195.1521 3404.0444,4195.3176 3404.3472,4195.3202 3404.3522,4195.4822 3404.665,4195.4847 3404.67,4195.6367 3404.9806,4195.6391 3404.9857,4195.7887 3405.3098,4195.791 3405.3149,4195.9278 3405.6294,4195.9301 3405.6347,4196.0624 3405.9592,4196.0644 3405.9644,4196.1877 3406.2869,4196.1897 3406.2922,4196.3093 3406.6276,4196.3111 3406.6329,4196.4181 3406.9559,4196.4199 3406.9613,4196.5249 3407.3038,4196.5264 3407.3092,4196.6196 3407.6399,4196.6211 3407.6454,4196.7095 3407.9885,4196.7108 3407.9939,4196.7898 3408.331,4196.7911 3408.3366,4196.8628 3408.6782,4196.8639 3408.6837,4196.9286 3409.0297,4196.9295 3409.0353,4196.9855 3409.3775,4196.9864 3409.3831,4197.0347 3409.7276,4197.0355 3409.7332,4197.0764 3410.081,4197.077 3410.0866,4197.1102 3410.4366,4197.1106 3410.4422,4197.1358 3410.789,4197.1361 3410.7948,4197.1534 3411.1452,4197.1536 3411.1508,4197.1629 3411.4973,4197.163 3411.5021,4197.165 3411.7449,4197.165 3852.6906,4197.1609 3853.0461,4197.1607 3853.0518,4197.1491 3853.3983,4197.1488 3853.4039,4197.129 3853.755,4197.1286 3853.7605,4197.1012 3854.1063,4197.1007 3854.1119,4197.0657 3854.4571,4197.0651 3854.4628,4197.0211 3854.8156,4197.0203 3854.8213,4196.9701 3855.1606,4196.9693 3855.166,4196.9096 3855.5165,4196.9085 3855.5221,4196.8431 3855.859,4196.842 3855.8645,4196.7675 3856.2077,4196.7662 3856.2132,4196.684 3856.5542,4196.6826 3856.5598,4196.5927 3856.8983,4196.5912 3856.9036,4196.4949 3857.2368,4196.4932 3857.2423,4196.3886 3857.5752,4196.3869 3857.5804,4196.2744 3857.9125,4196.2725 3857.9179,4196.1525 3858.2474,4196.1505 3858.2528,4196.0239 3858.577,4196.0218 3858.5822,4195.8888 3858.9019,4195.8866 3858.9071,4195.7433 3859.2305,4195.7409 3859.2356,4195.5938 3859.5488,4195.5913 3859.5538,4195.4346 3859.8687,4195.432 3859.8739,4195.2697 3860.182,4195.267 3860.1868,4195.0972 3860.4925,4195.0945 3860.4974,4194.9188 3860.7977,4194.9158 3860.8026,4194.7313 3861.1018,4194.7283 3861.1066,4194.5405 3861.3964,4194.5375 3861.4009,4194.3377 3861.6949,4194.3344 3861.6996,4194.134 3861.9805,4194.1307 3861.985,4193.9196 3862.2671,4193.9162 3862.2716,4193.7056 3862.5403,4193.7021 3862.5447,4193.4736 3862.8229,4193.47 3862.8271,4193.247 3863.0866,4193.2433 3863.0908,4193.0087 3863.3517,4193.0049 3863.3559,4192.7651 3863.6106,4192.7613 3863.6146,4192.515 3863.8648,4192.5109 3863.8689,4192.2617 3864.1107,4192.2577 3864.1146,4192.003 3864.351,4191.9989 3864.3547,4191.734 3864.5896,4191.7298 3864.5933,4191.4676 3864.8156,4191.4633 3864.8193,4191.1877 3865.0423,4191.1832 3865.0457,4190.9094 3865.2575,4190.9049 3865.2609,4190.6234 3865.4684,4190.6189 3865.4716,4190.33 3865.6748,4190.3254 3865.678,4190.0375 3865.8709,4190.0328 3865.874,4189.7409 3866.0603,4189.736 3866.0634,4189.4366 3866.2449,4189.4318 3866.2477,4189.1255 3866.4243,4189.1205 3866.4271,4188.8177 3866.5926,4188.8127 3866.5952,4188.4999 3866.7572,4188.4949 3866.7597,4188.1843 3866.9117,4188.1792 3866.9142,4187.8559 3867.0634,4187.8509 3867.0656,4187.5356 3867.2028,4187.5302 3867.2051,4187.2057 3867.3374,4187.2005 3867.3394,4186.878 3867.4627,4186.8727 3867.4647,4186.5373 3867.5843,4186.5319 3867.5862,4186.2071 3867.6937,4186.2018 3867.6953,4185.8611 3867.7998,4185.8557 3867.8014,4185.525 3867.8946,4185.5195 3867.8961,4185.1764 3867.9845,4185.171 3867.9858,4184.8339 3868.0648,4184.8283 3868.0661,4184.4867 3868.1378,4184.4812 3868.1389,4184.1352 3868.2036,4184.1296 3868.2045,4183.7874 3868.2605,4183.7818 3868.2614,4183.4373 3868.3097,4183.4317 3868.3105,4183.0839 3868.3514,4183.0783 3868.352,4182.7283 3868.3852,4182.7227
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

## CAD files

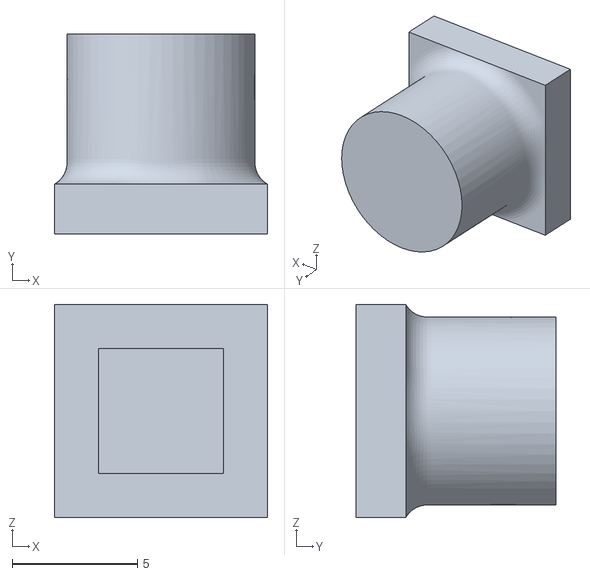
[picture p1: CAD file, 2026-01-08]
button_cap_2.STL
8.50 x 8.00 x 8.50

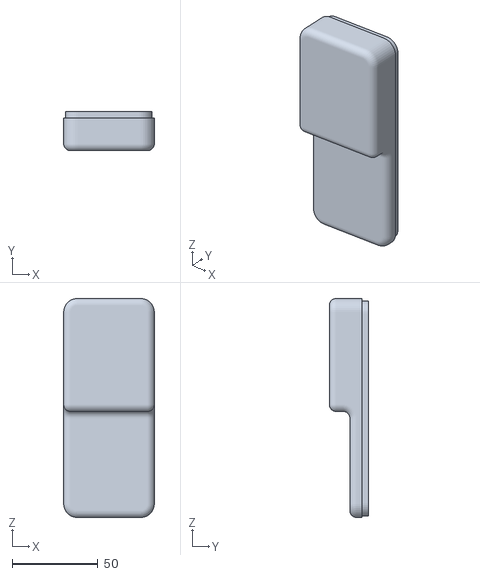
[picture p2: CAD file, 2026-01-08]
gameboy_bottom_2.STL
53.0 x 23.0 x 128.0

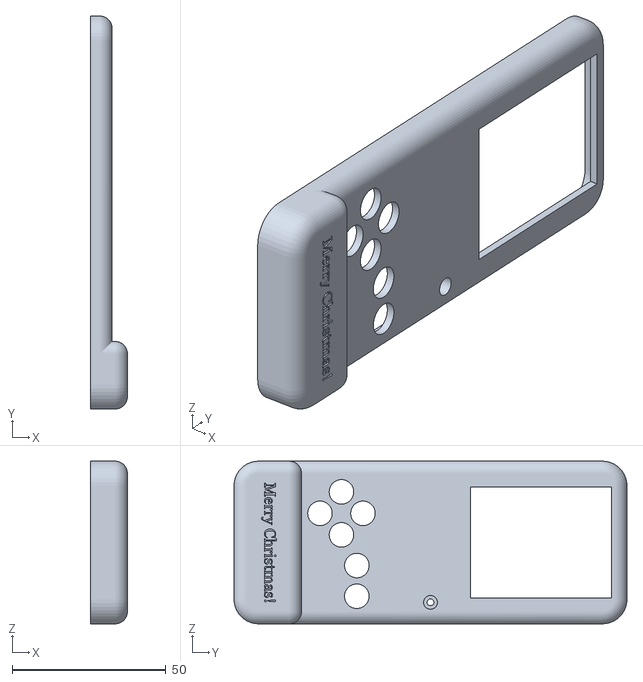
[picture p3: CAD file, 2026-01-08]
gameboy_top_v2.STL
12.0 x 128.0 x 53.0

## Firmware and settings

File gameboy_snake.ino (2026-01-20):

#include <Adafruit_GFX.h>      // Include Adafruit Core graphics library
#include <Adafruit_ST7789.h>   // Include Adafruit Hardware-specific library for ST7789
#include <SPI.h>               // Include Arduino SPI library

// Define ST7789 display pin connection
#define TFT_CS     10   
#define TFT_RST     8   // Or set to -1 and connect to Arduino RESET pin
#define TFT_DC       9

// Initialize the ST7789 display library with previously defined connections
Adafruit_ST7789 tft = Adafruit_ST7789(TFT_CS, TFT_DC, TFT_RST);
int inputs[6] = {HIGH, HIGH, HIGH, HIGH, HIGH, HIGH};

void setup() {
  // put your setup code here, to run once:
  //buttons
  pinMode(2, INPUT_PULLUP); //up
  pinMode(4, INPUT_PULLUP); //down
  pinMode(3, INPUT_PULLUP); //right
  pinMode(5, INPUT_PULLUP); //left
  pinMode(6, INPUT_PULLUP); //start
  pinMode(7, INPUT_PULLUP); //back

  // Initialize the ST7789 TFT display
  tft.init(240, 320);   // Init ST7789 240x240

  // if the screen is flipped, remove this command
  tft.setRotation(2);
}

void loop() {
  // put your main code here, to run repeatedly:]
  menu();
  snake();
}

void write_text(char *text, uint16_t color, bool wrap, int size, int x, int y) {
  tft.setCursor(x, y);
  tft.setTextColor(color);
  tft.setTextWrap(wrap);
  tft.setTextSize(size);
  tft.print(text);
}

void getInputs(int (& inputarray) [6]) {
  //start, back, up, down, left, right
  inputarray[0] = digitalRead(6);
  inputarray[1] = digitalRead(7);
  inputarray[2] = digitalRead(2);
  inputarray[3] = digitalRead(4);
  inputarray[4] = digitalRead(5);
  inputarray[5] = digitalRead(3);
}

void menu() {
  tft.fillScreen(ST77XX_WHITE);
  write_text("Merry", ST77XX_GREEN, true, 4, 10, 10);
  write_text("Christmas!", ST77XX_RED, false, 4, 10, 50);
  write_text("Press start to play snake", ST77XX_BLACK, true, 2, 10, 100);
  bool start = false;
  while (start == false) {
    getInputs(inputs);
    if (inputs[0] == LOW) {
      start = true;
    }
  }
}

void snake() {
  int size = 8; //change to 12 or equivalent for larger gameplay
  int x = size*8;
  int y = size*10 + 20;
  bool running = true;
  bool exit_now = false;
  bool changed = false;
  int x_movement = size;
  int y_movement = 0;
  unsigned long prev_millis = millis();
  int interval = 60;
  unsigned long current_millis;
  #define MAX_TAIL 100
  int tail_x[MAX_TAIL];
  int tail_y[MAX_TAIL];
  int tail_length = 1;
  tail_x[0] = x-size;
  tail_y[0] = y;
  int apple[2] = {random(240/size)*size, random(300/size) * size + 20};

  tft.fillScreen(ST77XX_BLACK);
  tft.drawRect(x, y, size, size, ST77XX_WHITE);
  tft.drawRect(apple[0], apple[1], size, size, ST77XX_RED);
  write_text("Score: ", ST77XX_WHITE, false, 2, 0, 0);
  write_text("0", ST77XX_WHITE, false, 2, 80, 0);

  while (running == true) {
    getInputs(inputs);
    //back
    if (inputs[1] == LOW) {
      running = false;
      exit_now = true; 
    }

    //up
    if (inputs[2] == LOW) {
      y_movement = -size;
      x_movement = 0;
    }

    //down
    if (inputs[3] == LOW) {
      y_movement = size;
      x_movement = 0;
    }

    //right
    if (inputs[5] == LOW) {
      y_movement = 0;
      x_movement = size;
    }

    //left
    if (inputs[4] == LOW) {
      y_movement = 0;
      x_movement = -size;
    }

    current_millis = millis();

    if (current_millis - prev_millis >= interval) {
      prev_millis = current_millis;

      //wall collision
      if (x < 0 || x >= 240 || y < 20 || y >= 320) {
        running = false;
      }

      //self-collision
      for (int i=0; i<tail_length; i++) {
        if (tail_x[i] == x && tail_y[i] == y) {
          running = false;
          break;
        }
      }

      //eats apple
      if (x == apple[0] && y == apple[1]) {
        if (tail_length < MAX_TAIL) {
          tail_length++;
        }

        apple[0] = random(240 / size) * size;
        apple[1] = random(300 / size) * size + 20;

        tft.fillRect(0, 0, 240, 20, ST77XX_BLACK);
        write_text("Score: ", ST77XX_WHITE, false, 2, 0, 0);

        char b[5];
        itoa(tail_length - 1, b, 10);
        write_text(b, ST77XX_WHITE, false, 2, 80, 0);
      }

      // erase last tail segment
      tft.drawRect(tail_x[tail_length - 1], tail_y[tail_length - 1], size, size, ST77XX_BLACK);
      for (int i = tail_length - 1; i > 0; i--) {
        tail_x[i] = tail_x[i - 1];
        tail_y[i] = tail_y[i - 1];
      }

      tail_x[0] = x;
      tail_y[0] = y;
      x = x + x_movement;
      y = y + y_movement;
      //tft.fillScreen(ST77XX_BLACK);
      tft.drawRect(x, y, size, size, ST77XX_WHITE); //draw new head
      tft.drawRect(apple[0], apple[1], size, size, ST77XX_RED); //draw apple
      }
    
  }
  if (exit_now == false) {
    tft.fillScreen(ST77XX_RED);
    write_text("Game Over", ST77XX_BLUE, false, 3, 0, 0);
    write_text("Score: ", ST77XX_WHITE, false, 2, 10, 100);
    char b[3];
    String str;
    str=String(tail_length-1);
    str.toCharArray(b,3);
    write_text(b, ST77XX_WHITE, false, 2, 80, 100);

    bool done = false;
    while (done == false) {
      getInputs(inputs);
      int s = 6;
      for (int i=0; i<6; i++){
        s -= inputs[i]; //Low(pressed) = 0, high(default) = 1
      }
      if (s > 0) {
        done = true;
      }
    }
  }
}

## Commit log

2025-11-28 Add wiring diagram and pcb imae
2025-11-28 upload gerber and 3d obj of pcb
2026-01-08 Uploaded stl files for case
    [button_cap_2.STL, gameboy_bottom_2.STL, gameboy_top_v2.STL]
2026-01-20 Revise README with project details and programming steps
    Updated project description and steps for programming the ATMEGA328 using ISP. Added wiring diagram and PCB download instructions.
